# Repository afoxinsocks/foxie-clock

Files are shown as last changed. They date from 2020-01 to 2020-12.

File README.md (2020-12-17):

# Foxie Clock

## A Nixie-like, retro, RGB LED, Arduino-powered clock

Welcome to the Foxie Clock, a fully open-source RGB clock with nixie-like edge-lit acrylic digits. Or... an RGB pixel display clock, if you like!

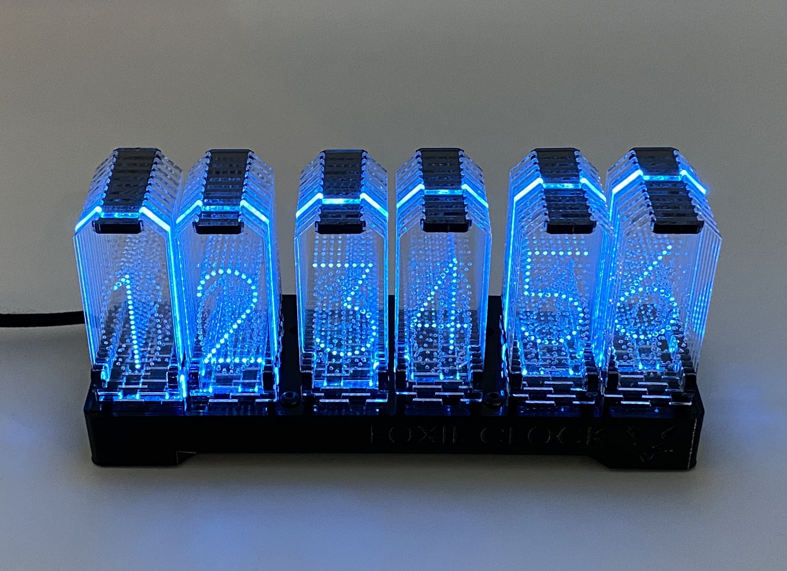
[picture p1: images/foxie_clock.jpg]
Foxie Clock Image

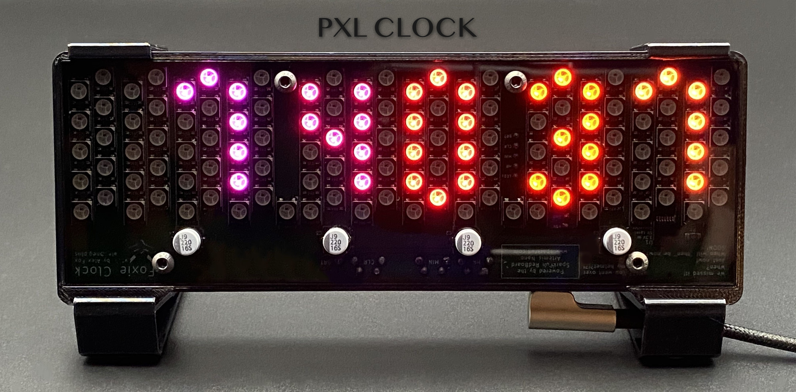
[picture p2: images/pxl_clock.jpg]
Foxie Clock Pixel Display


## Looks

With a look inspired by old nixie tubes and with capacitors protruding through the surface like vacuum tubes, the Foxie Clock is a fun, colorful way to display the time at your desk, office, or anywhere. Brightness, color, and time are all adjustable directly with 4 buttons on the back. [Using the clock is very easy](USAGE.md), with 4 buttons on the back providing various functionality for setting time, animation modes, colors, and brightness, 12/24h mode, PXL mode, and more.

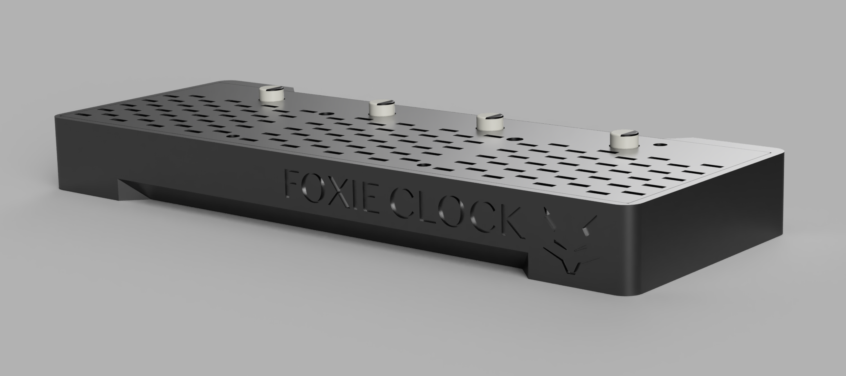
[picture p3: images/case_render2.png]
Foxie Clock Case Render Image2


# [Get your own](https://www.foxieproducts.com/)

Head [over to Foxie Products](https://www.foxieproducts.com/) to order your own Foxie Clock kit.

## 3D Print your own case or modify it yourself!

All .STL models and the full Fusion360 project and the .step files are also available for anyone wanting to make changes to the design more easily. Head over to [Thingiverse](https://www.thingiverse.com/thing:4114349) to download.

## Easy to assemble

The clock is [easy to assemble](ASSEMBLY.md) and looks beautiful when complete.

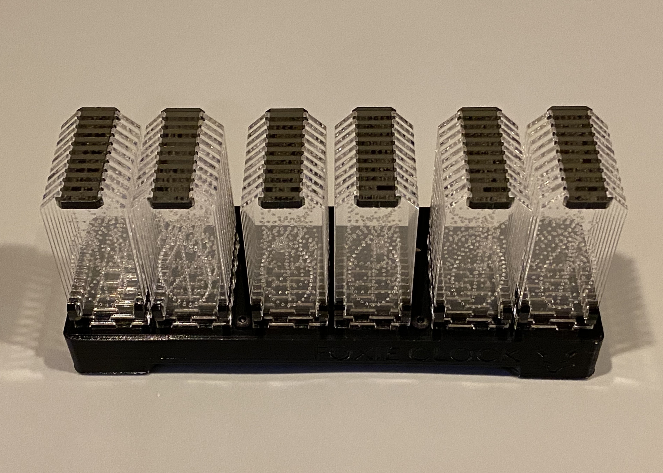
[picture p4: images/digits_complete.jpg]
Foxie Clock Case Assembled


The case is 3D printed and is included with the kit.

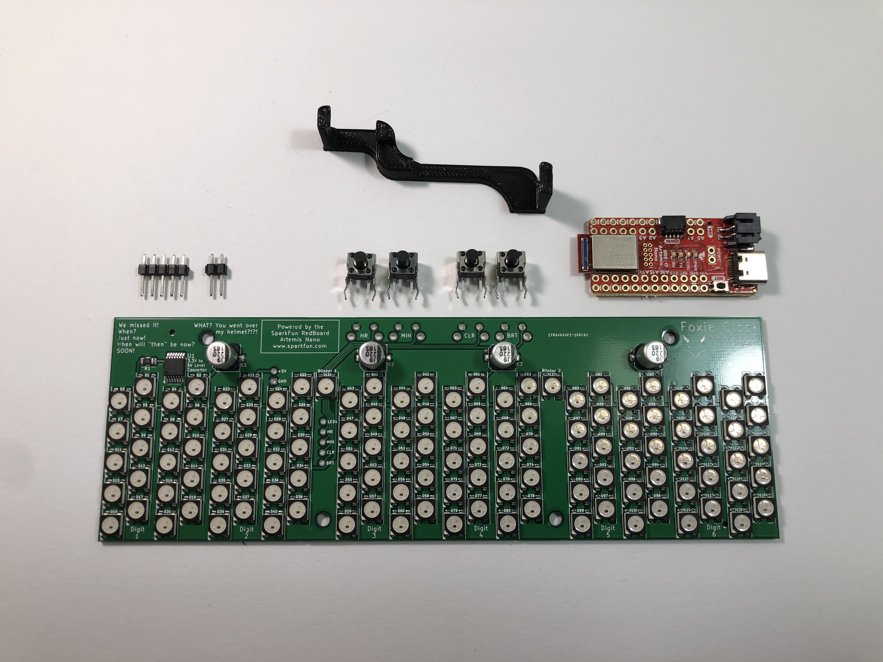
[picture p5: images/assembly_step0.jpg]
Foxie Clock Case Assembly


The circuit board can be ordered fully soldered, or if you like, you can solder the 4 buttons and RedBoard Nano yourself, using the plentiful pictures in the [electronics assembly guide](ELECTRONICS.md).

## Easy to hack

The Foxie Clock is powered by a SparkFun RedBoard Artemis Nano (https://www.sparkfun.com/products/15443), an extremely cool, fully Arduino-compatible board that supports Bluetooth LE 5.0 and much, much more. It is included in every Foxie Clock kit, along with everything you need (including USB-C cable) to get running.

## Fully Open Source

The Foxie Clock PCB and firmware were developed using Open Source software. The source code, laser cutting files, PCB design, and documentation for assembly are all freely available here.

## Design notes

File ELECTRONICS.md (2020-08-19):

# Electronics

Time to dust off your soldering skills, we've just got a few buttons to solder and finally need to attach the RedBoard Nano to the Foxie Clock PCB. 

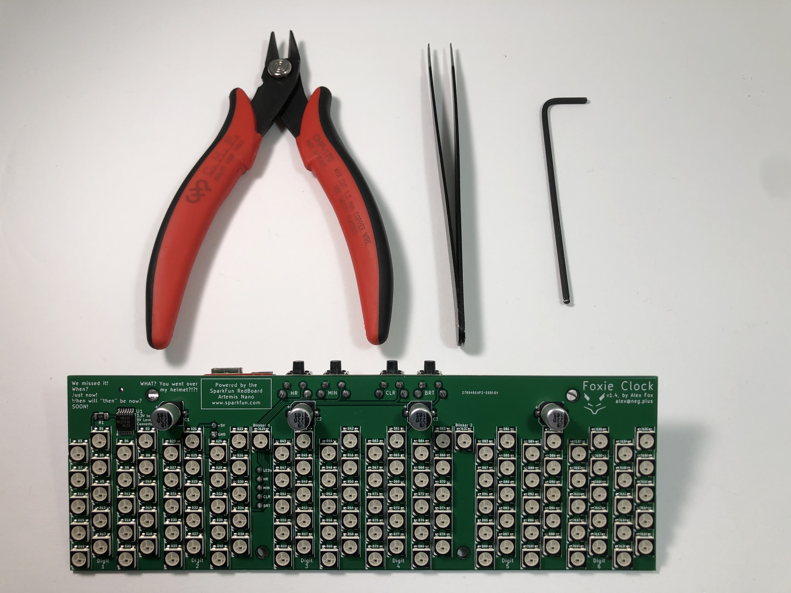
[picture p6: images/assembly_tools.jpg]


Included parts:
* One 2-pin header
* One 5-pin header
* 4 buttons
* One RedBoard Nano
* One "assembly helper"

**Note:** The clippers are necessary to trim the tops of the button pins, otherwise the lid will not sit correctly.

Parts

## Step 1

Insert the 4 buttons into the holes on the bottom of the PCB.

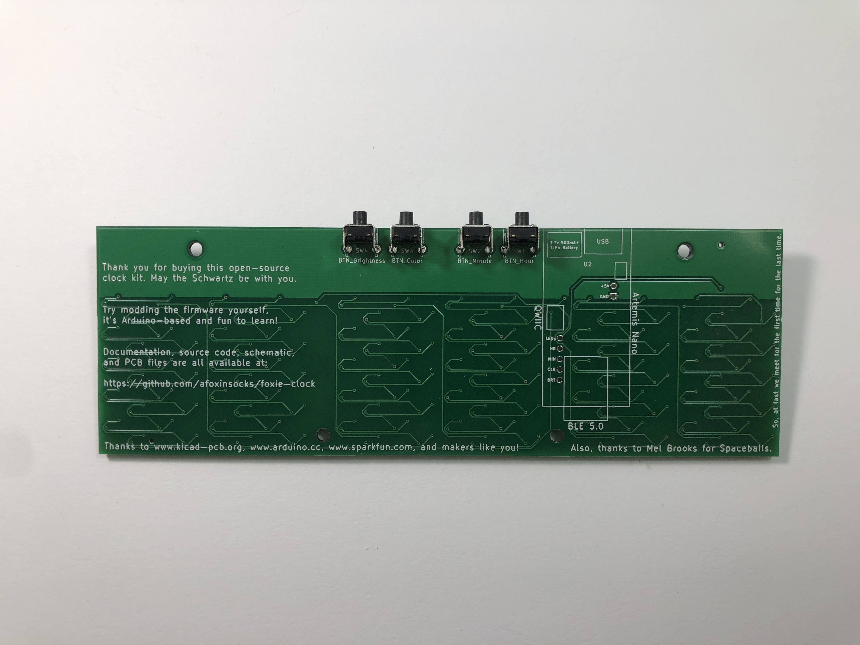
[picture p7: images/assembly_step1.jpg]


## Step 2

Ensure that the buttons are completely flat against the PCB.

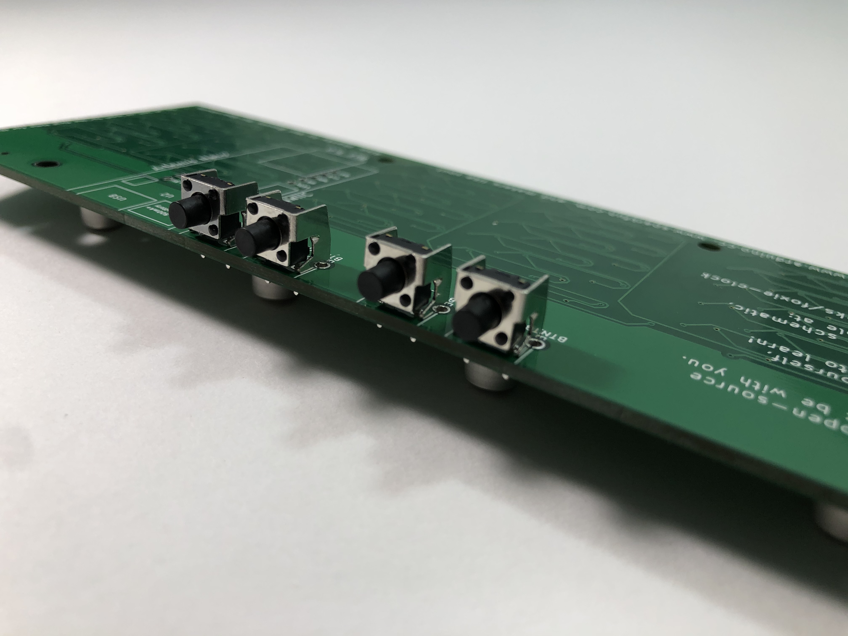
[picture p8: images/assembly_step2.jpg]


## Step 3

Turn the board over with the buttons in it. They are a snug fit and **should** stay in place.

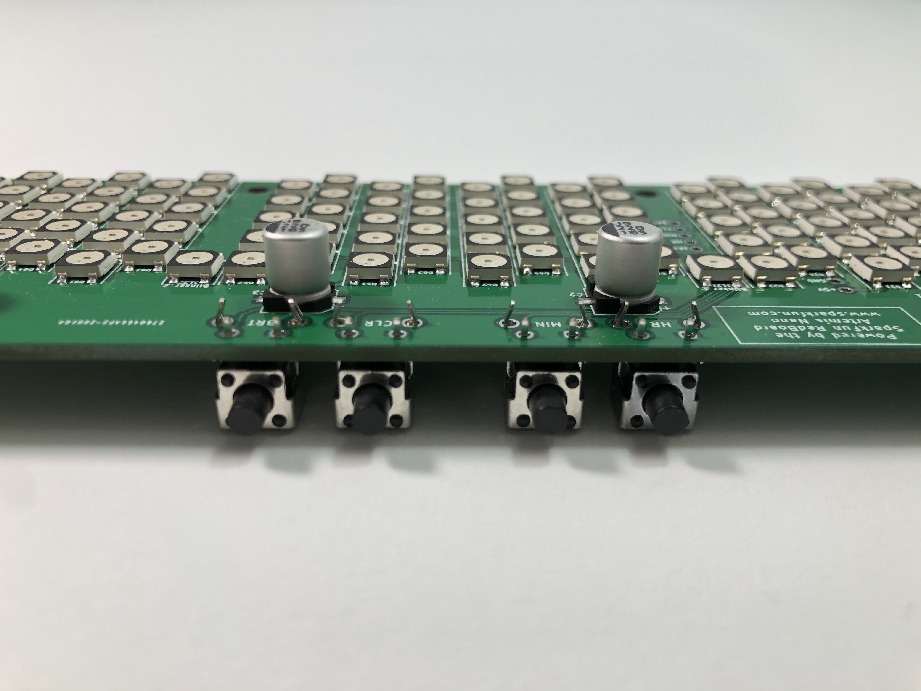
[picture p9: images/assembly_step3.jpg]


## Step 4

Begin by soldering one of the pins for each button. After doing so, double check that the buttons are still right against the PCB -- the tolerances on the back of the 3d printed case require these buttons to be exactly flush to the PCB. 

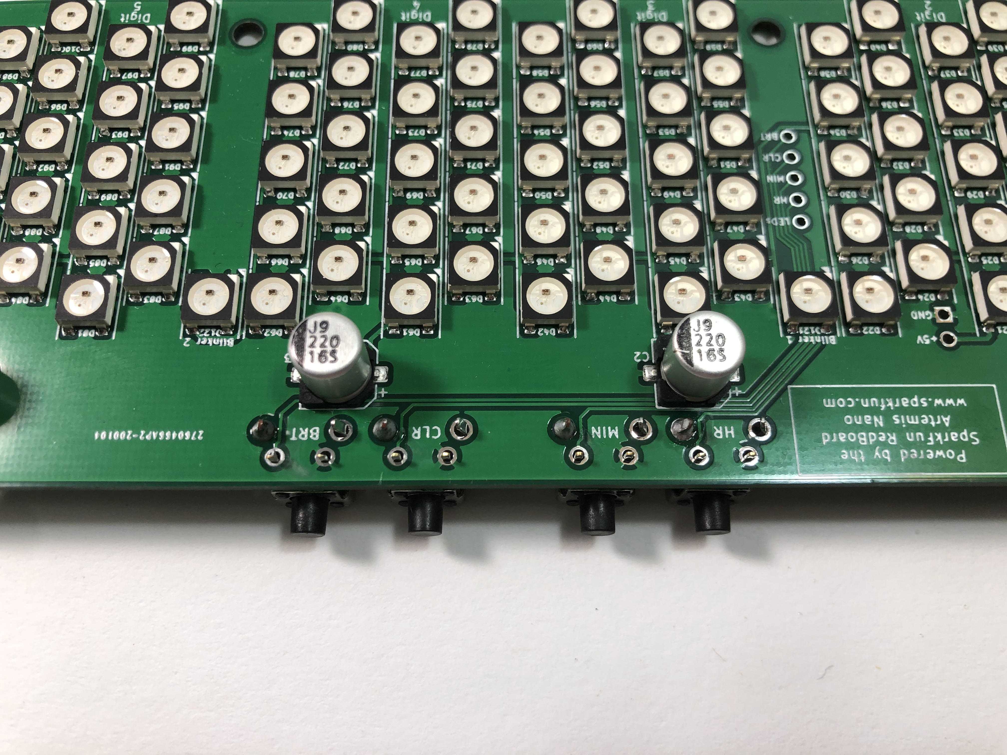
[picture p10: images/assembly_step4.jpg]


## Step 5

After verifying (and resoldering, if necessary) the single pin holding each of the buttons next to the PCB, go ahead and solder the other 3 pins for each button.

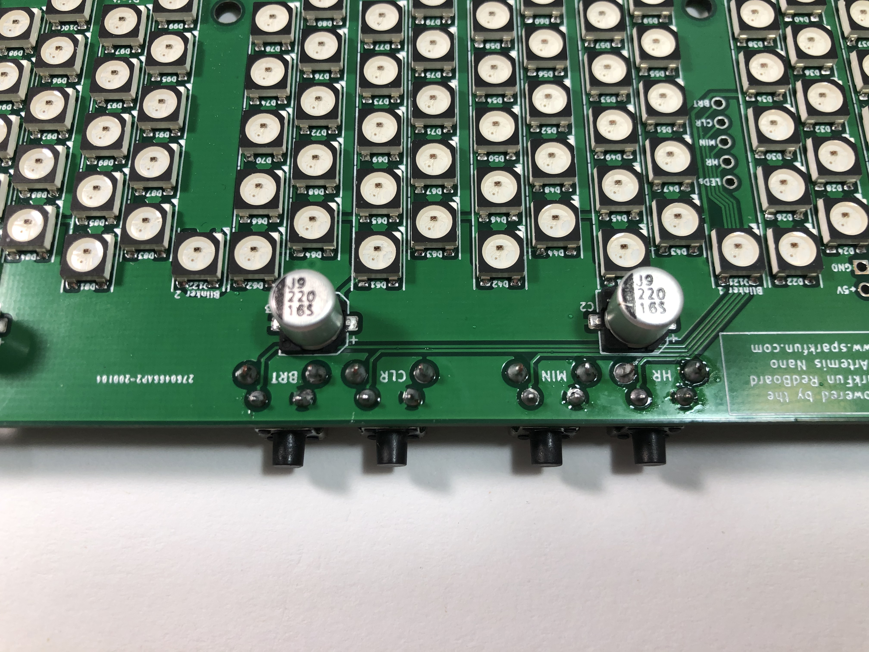
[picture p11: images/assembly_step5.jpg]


## Step 6

Prepare the RedBoard Nano by inserting the two headers into the *bottom* of the RedBoard (the side without the USB connector). The 2-pin header goes into the VIN and GND holes. The 5-pin header goes into the holes labled `6 A5 4 A3 A2`. **Do not solder yet!**

**NOTE**: Make sure the long pins of the jumpers are going through the RedBoard to the "top" side, otherwise you'll have to clip them off later when we trim the button pins.

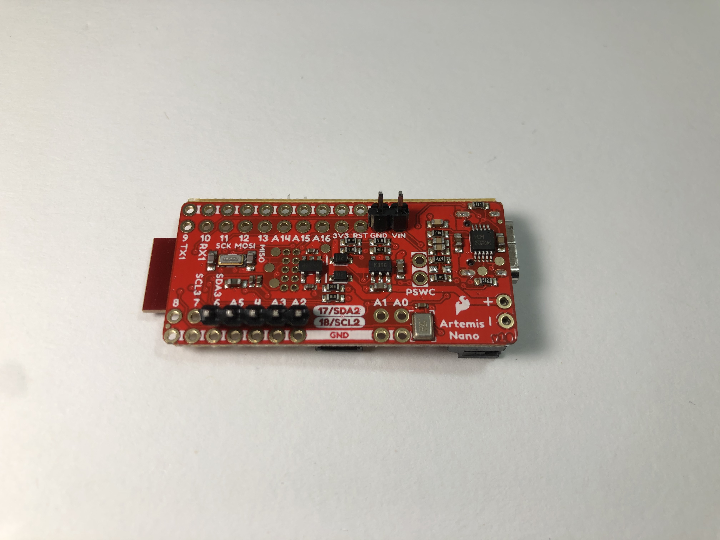
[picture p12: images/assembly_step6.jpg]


## Step 7

Holding the Foxie Clock PCB vertically, carefully insert the pins from the RedBoard into the Foxie Clock board, then set it down.

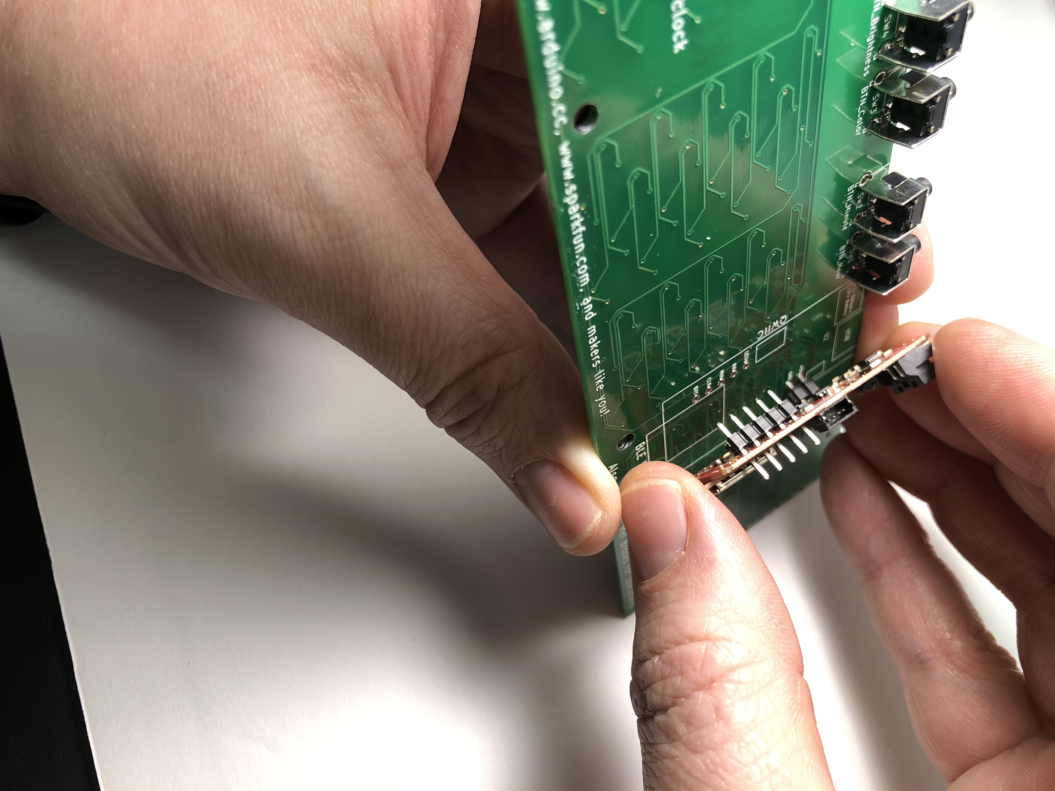
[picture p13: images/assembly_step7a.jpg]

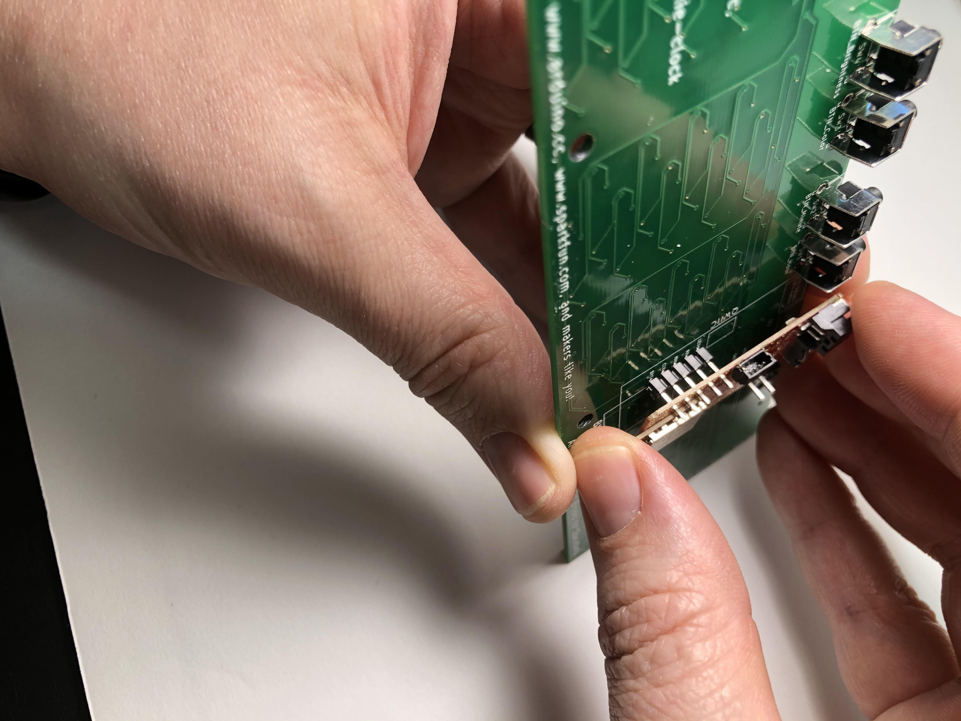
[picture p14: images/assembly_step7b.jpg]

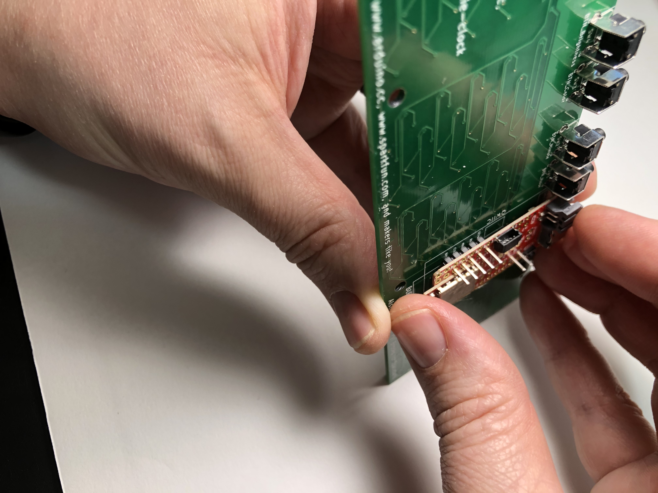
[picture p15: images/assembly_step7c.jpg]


## Step 8

Attach the Assembly helper to hold the RedBoard Nano to the PCB so that it is properly positioned. As with the buttons, it is important that the RedBoard be correctly positioned **before** soldering so that the USB port is in the correct place for
the USB port hole in the back of the case.

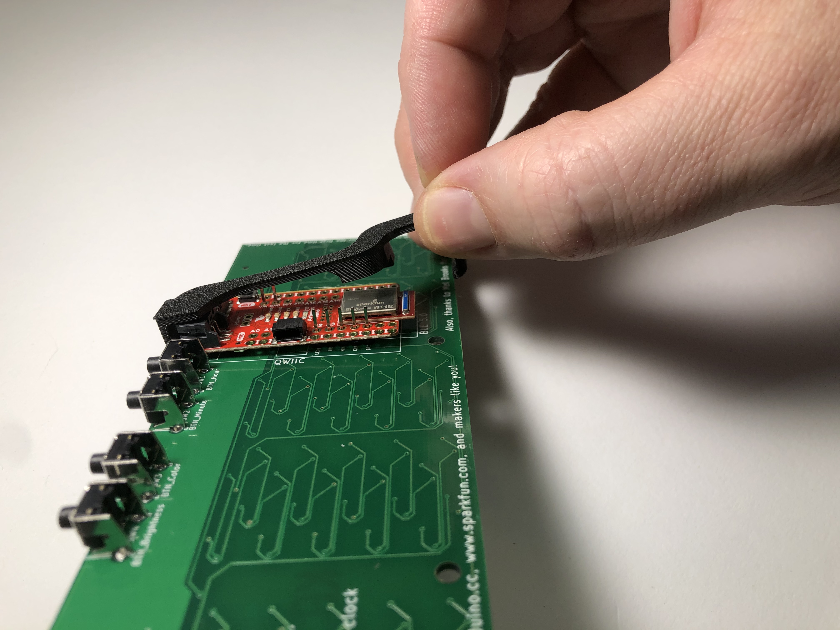
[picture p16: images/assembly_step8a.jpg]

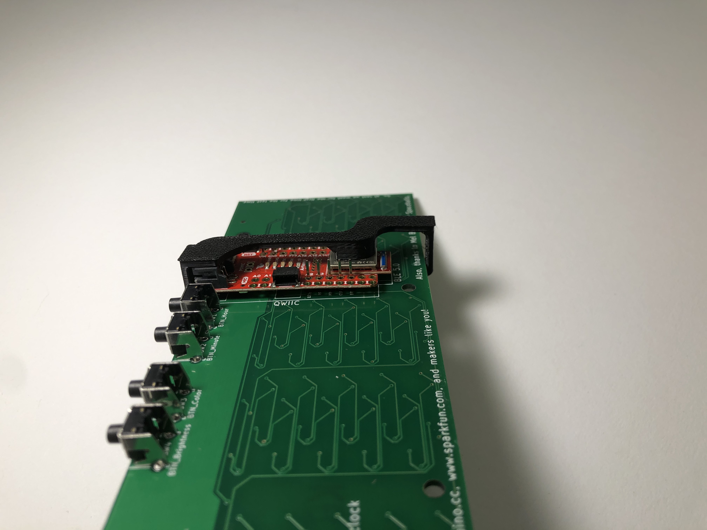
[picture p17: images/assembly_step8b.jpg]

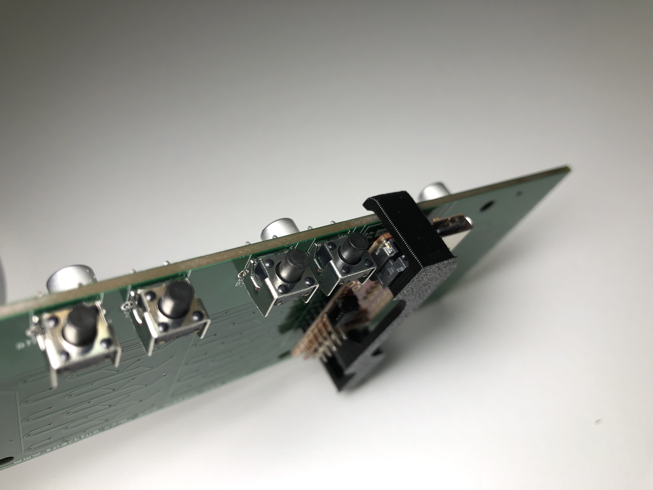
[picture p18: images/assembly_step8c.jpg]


## Step 9

Solder the 2-pin and 5-pin headers on the bottom of the RedBoard.

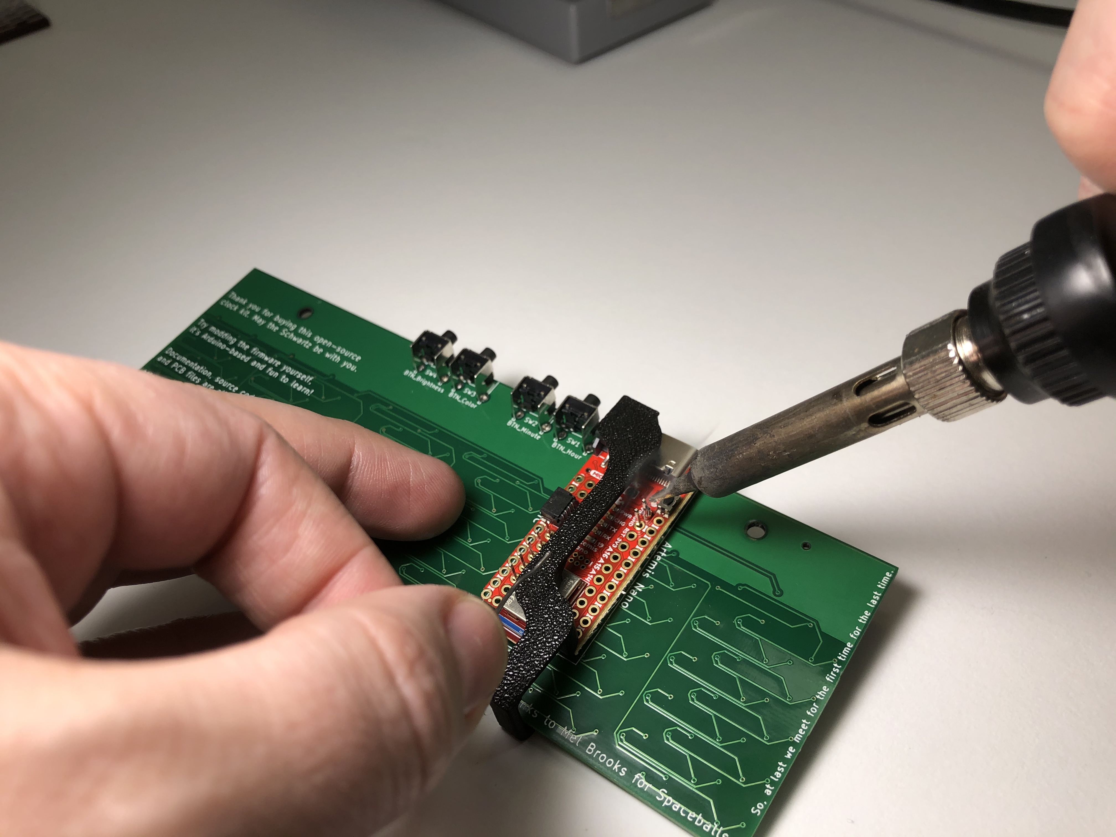
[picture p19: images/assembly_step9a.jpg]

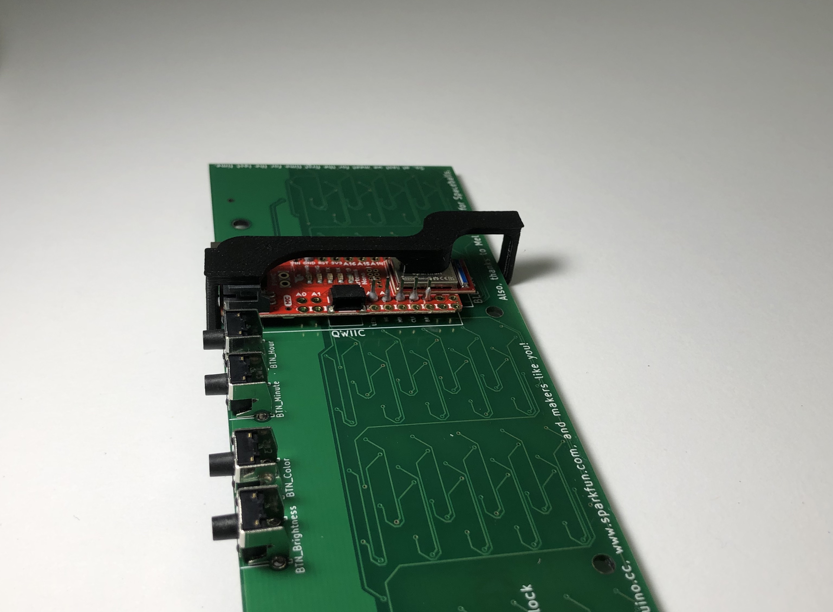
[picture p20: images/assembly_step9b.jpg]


## Step 10

Carefully turn the board over, keeping the assembly helper attached, and solder the 2-pin and 5-pin headers to the top of the PCB.

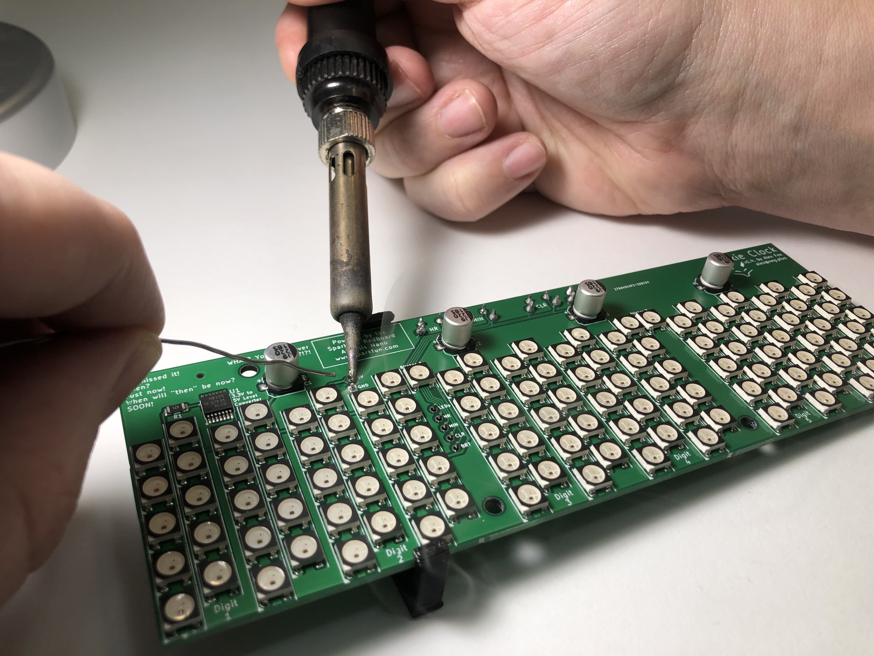
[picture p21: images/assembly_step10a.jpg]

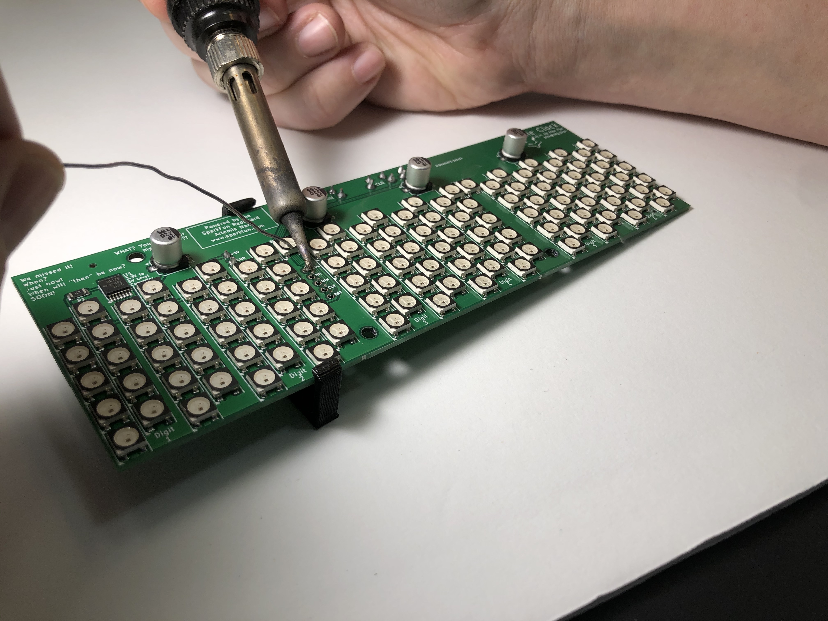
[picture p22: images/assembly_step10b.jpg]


## Step 11

Remove the assembly helper, and marvel at your perfectly placed RedBoard Nano on 7 little stilts.

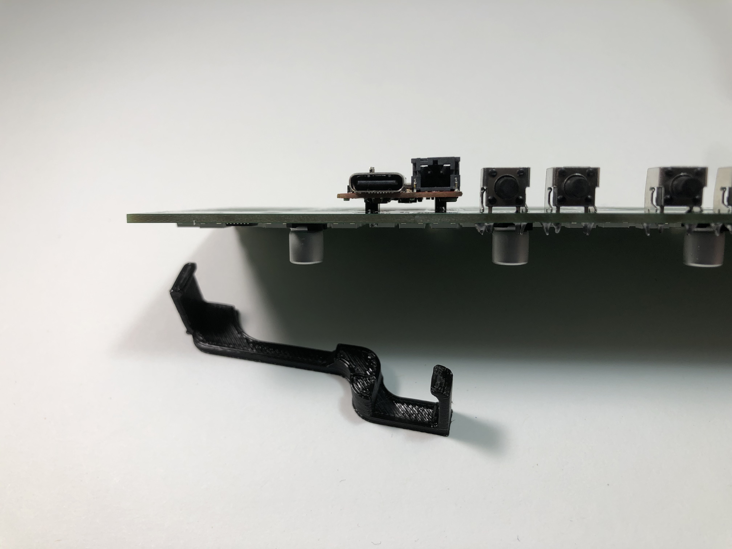
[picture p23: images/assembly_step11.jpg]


## Step 12

Trim the excess height of the button leads. 

**NOTE:** It is not important to get them flush. They just need to be trimmed to be about the same height as the LEDs, so that the lid sits correctly inside the case.

**NOTE:** It's a good idea to reflow the solder on these joints after being trimmed.

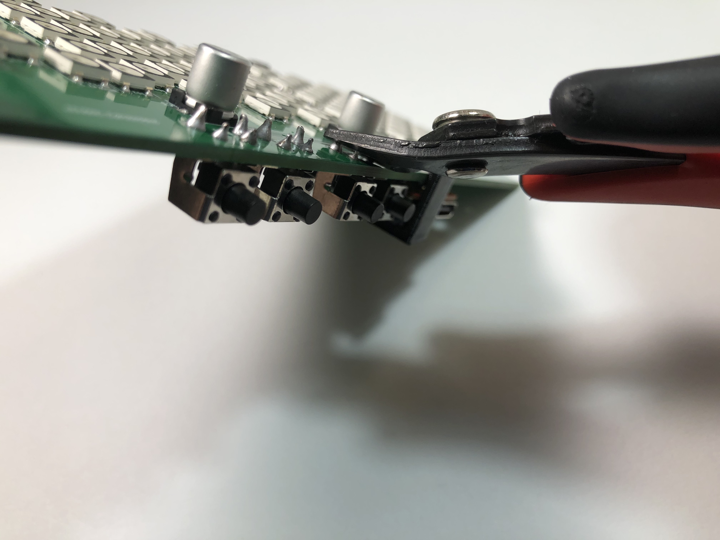
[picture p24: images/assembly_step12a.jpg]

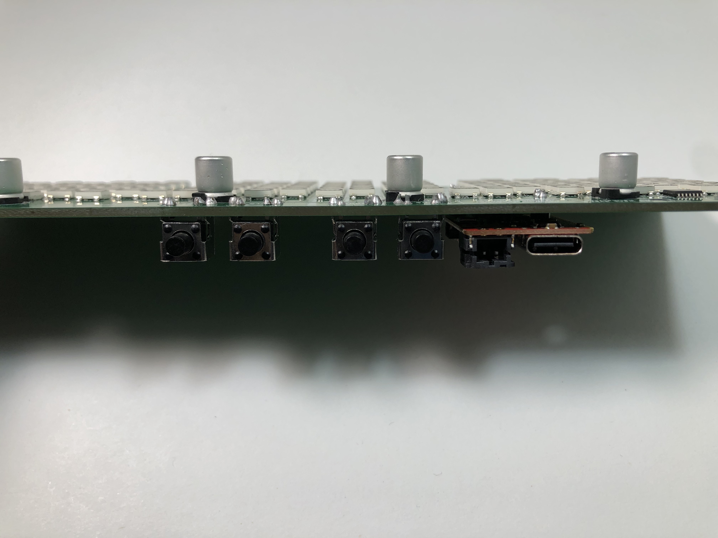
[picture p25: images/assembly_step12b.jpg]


## Step 13

Congratulations, the electronics are ready to go into the case!

Begin by placing the PCB in the rear top corners of the case.
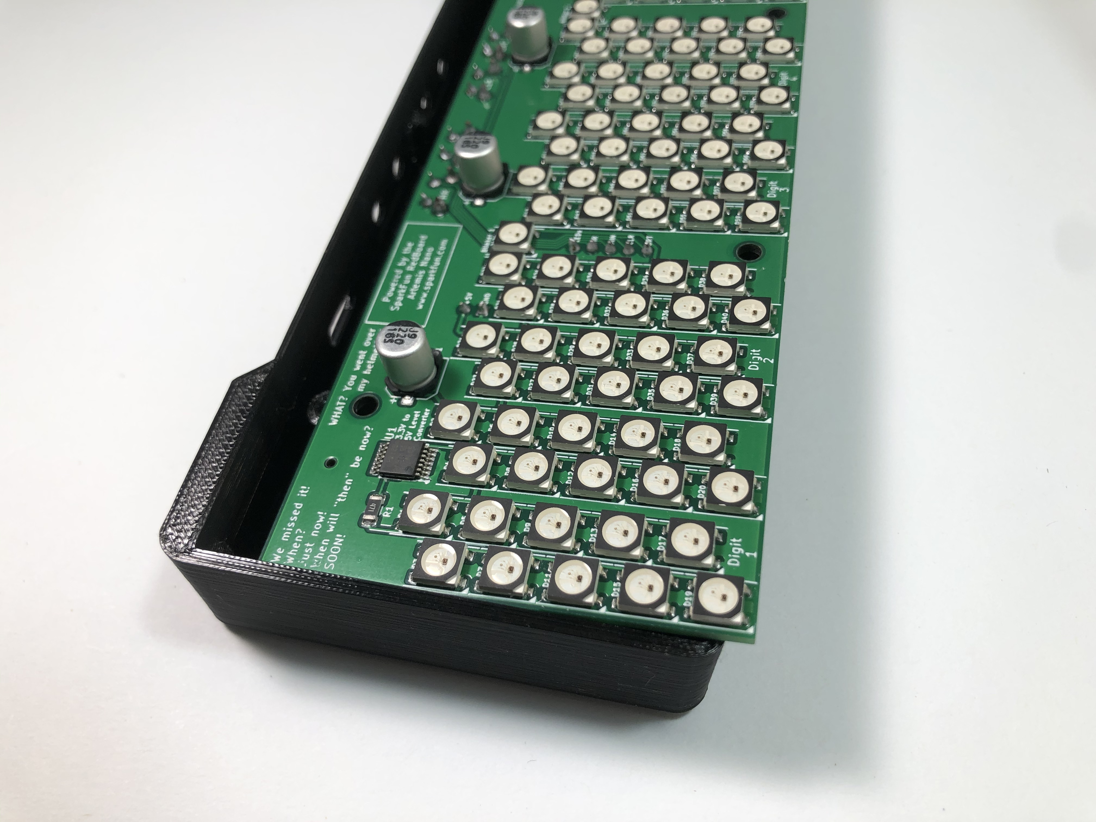
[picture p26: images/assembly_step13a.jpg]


Carefully push the buttons into the button holes.
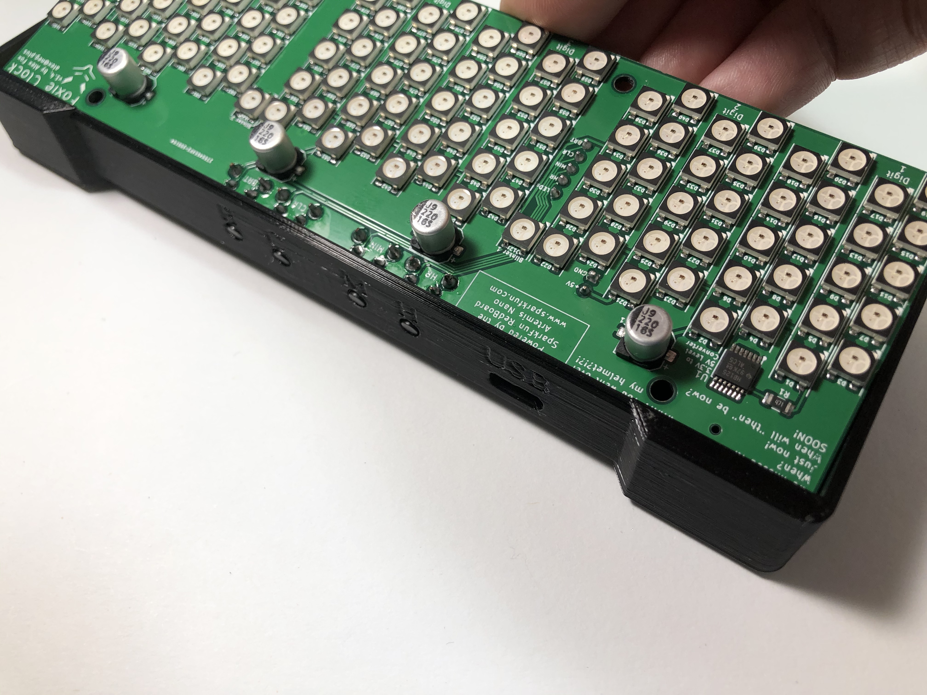
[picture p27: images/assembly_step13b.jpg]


The board should drop straight in at this point, if the buttons and Nano are close to being correctly placed.
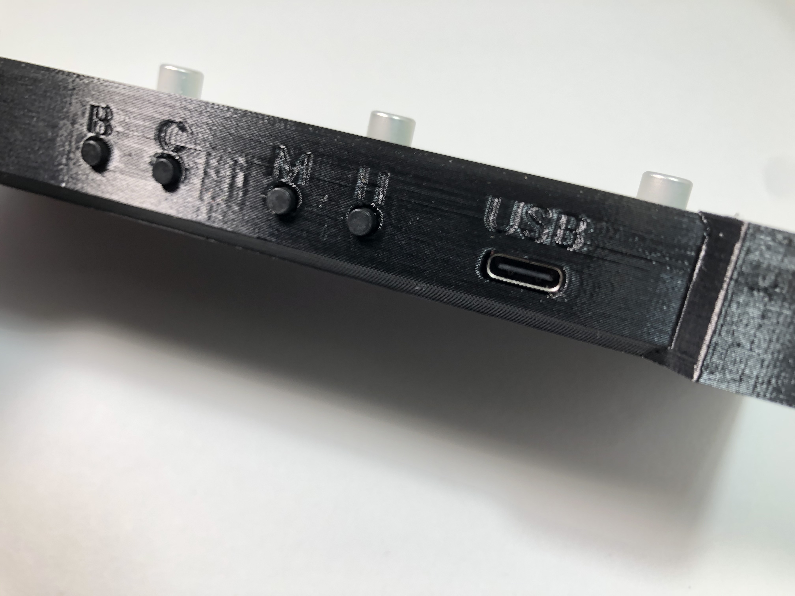
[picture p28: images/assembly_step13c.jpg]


Make sure that the board is completely flush with the inside back of the case.
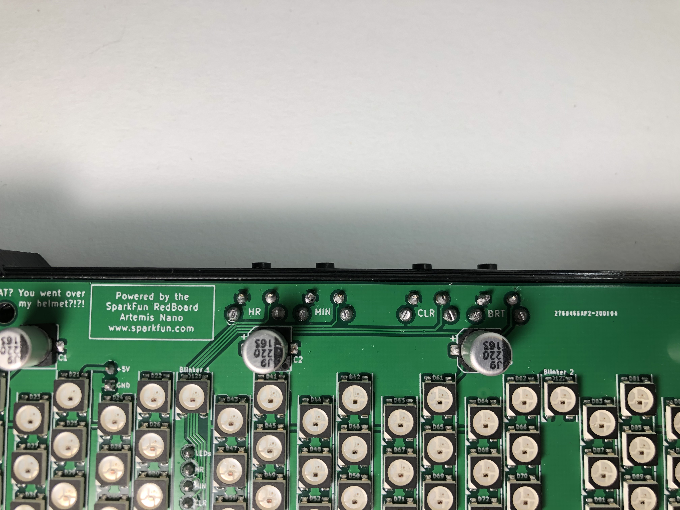
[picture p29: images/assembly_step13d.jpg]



You can now put the lid on top of the PCB and insert the 4 bolts, if desired. Make sure not to overtighten the bolts.

## Step 14

Firmware isn't yet programmed onto the RedBoard, [so let's take care of that now.](INSTALLING.md).

## Step 15
[Continue onto final assembly](ASSEMBLY.md)

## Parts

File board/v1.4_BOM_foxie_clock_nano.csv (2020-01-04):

Comment | Designator | Footprint | LCSC | LCSC
220uF | C1,C2,C3,C4 | Capacitor_SMD:CP_Elec_6.3x7.7 |  | C127327
WS2812B | D2,D1,D4,D3,D6,D5,D9,D10,D7,D8,D12,D11,D14,D13,D16,D15,D19,D20,D17,D18,D22,D21,D24,D23,D26,D25,D29,D30,D27,D28,D32,D31,D34,D33,D36,D35,D39,D40,D37,D38,D42,D41,D44,D43,D46,D45,D49,D50,D47,D48,D52,D51,D54,D53,D56,D55,D59,D60,D57,D58,D62,D61,D64,D63,D66,D65,D69,D70,D67,D68,D72,D71,D74,D73,D76,D75,D79,D80,D77,D78,D82,D81,D84,D83,D86,D85,D89,D90,D87,D88,D92,D91,D94,D93,D96,D95,D99,D100,D97,D98,D102,D101,D104,D103,D106,D105,D109,D110,D107,D108,D112,D111,D114,D113,D116,D115,D119,D120,D117,D118,D122,D121 | foxie_clock_nano:LED_WS2812B_PLCC4_5.0x5.0mm_P3.2mm |  | C114586
470 | R1 | Resistor_SMD:R_1206_3216Metric |  | C25383
BTN_Hour | SW1 | Button_Switch_THT:SW_Tactile_SPST_Angled_PTS645Vx58-2LFS
BTN_Minute | SW2 | Button_Switch_THT:SW_Tactile_SPST_Angled_PTS645Vx58-2LFS
BTN_Color | SW3 | Button_Switch_THT:SW_Tactile_SPST_Angled_PTS645Vx58-2LFS
BTN_Brightness | SW4 | Button_Switch_THT:SW_Tactile_SPST_Angled_PTS645Vx58-2LFS
SN74AHCT125N | U1 | Package_SO:TSSOP-14_4.4x5mm_P0.65mm |  | C36365
Artemis-Nano | U2 | foxie_clock_nano:Artemis-Nano

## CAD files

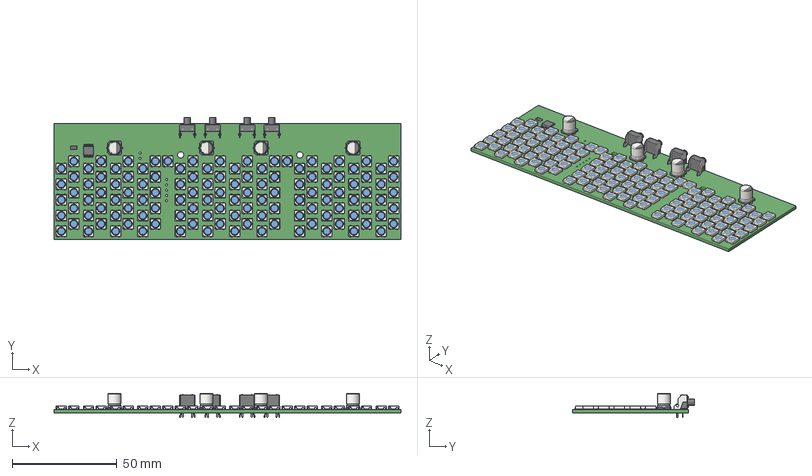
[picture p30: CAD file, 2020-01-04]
board/foxie_clock_nano_v1.step
166.0 x 58.5 x 11.7 mm

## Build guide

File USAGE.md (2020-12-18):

# How to use the clock

## Setting the time:
1. Hold H/Hour button down for 1+ seconds to enter Set Time mode (The H button is the closest to the USB port)
2. Digit colors will change and the seconds will stop counting
3. Use H and M buttons to set the correct Hours and Minutes -- Holding M will advance minutes quickly. Note that H does not have the same fast functionality.
4. Hold H button down again for 1+ seconds to return to normal mode - the seconds will resume counting and the clock color will change back to the previous setting.

## Changing the brightness
Press the `B` button to set the brightness. There are 8 levels, and the current brightness is remembered when powering off the clock.

## Changing the color
The `C` button is typically used for changing the color of the digits, but its use depends on the animation mode the clock is currently using.

### Animation modes:
Animation modes can be changed by pressing the `M` button while not in `Set Time` mode. The current animation mode number will be displayed after each button press.

* ANIM_NONE (0): No animation, and pressing the C button will manually change the colors for all digits at once. The current color setting is saved when changed.
* ANIM_ZIPPY(1): An animation that causes movement through all the numbers every time a number changes.
* ANIM_GLOW (2): Similar to ANIM_NONE, except the digits briefly dim and glow every couple seconds. C button changes colors for all digits at once
* ANIM_CYCLE_COLORS (3): The colors will cycle across the digits as each second changes and the C button will not do much other than briefly flash a color.
* ANIM_CYCLE_FLOW_LEFT (4): The color of the furthest right digit will cycle each second and as each digit rolls from 9 back to 0, that digit's color will be copied to the left.
* ANIM_RAINBOW (5): All digits will continuously gently cycle colors while the clock is running.
* ... more modes are coming!

Changing the animation mode will be possible via the mobile app within the coming months, and can also be manually set via the  `setup()` function in `firmware.ino` and then [re-upload the firmware](INSTALLING.md).

## Toggling between edge-lit and PXL mode
Hold M+C for 1 second to toggle. This is useful when you switch between the acrylic digit base and the PXL cover.

## Toggling 12/24H mode
Hold H+M for 1 second.

## Flipping the display
Hold C+B for 1 second to toggle. This is useful if you want to put your digits in the reverse order, to keep the buttons at the front. Also, useful for PXL mode.

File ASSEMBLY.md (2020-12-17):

# Electronics

If your kit requires soldering the buttons and RedBoard Nano to the Foxie Clock PCB, head to 
[the electronics assembly instructions](ELECTRONICS.md) and complete that step first.

# Digits

For digit assembly, the **most important** thing to remember is to keep the digits clean. If the digits get
fingerprints on them, it becomes difficult to see the numbers through several layers. They can be carefully
cleaned with lens wipes. All kits include 2 nitrile gloves (non-powder, non-latex) to assist with assembly.

You'll need the fully assembled Foxie Clock board, a 2mm hex wrench, a utility knife or Xacto knife, and finally, sharp tweezers are extremely helpful. 

## Step 1

Set out the 6 sets of digits and put on the nitrile gloves gloves. This part is a little tedious but if you are careful, you can peel the film off each side as one piece, in less than a minute. Ideally, *do not* break the digits apart before this step.

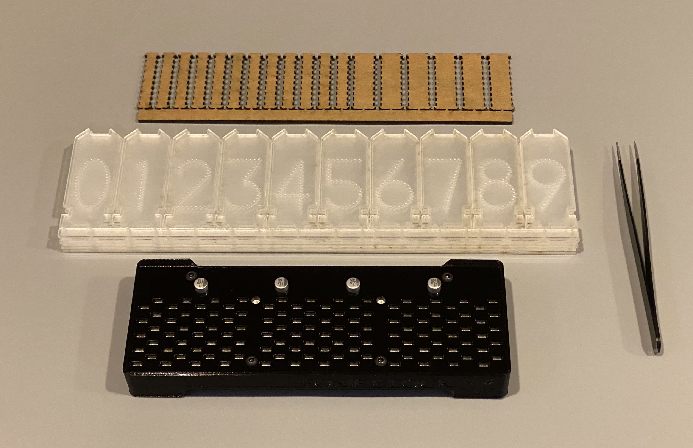
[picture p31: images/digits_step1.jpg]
Lay out stacks of digits


## Step 2

Carefully peel back the film on the "rail" and then peel carefully along the rail to the other side. After that, peel toward the top of the digits.

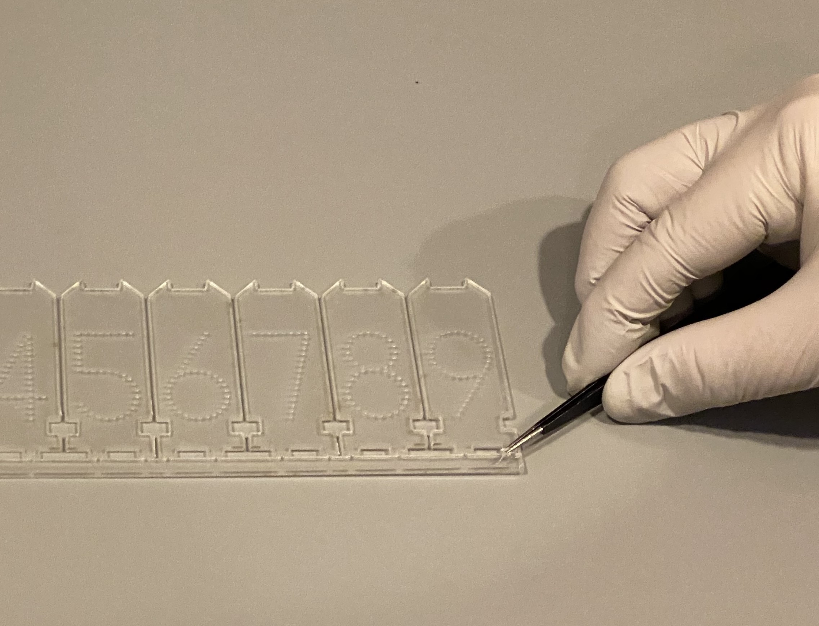
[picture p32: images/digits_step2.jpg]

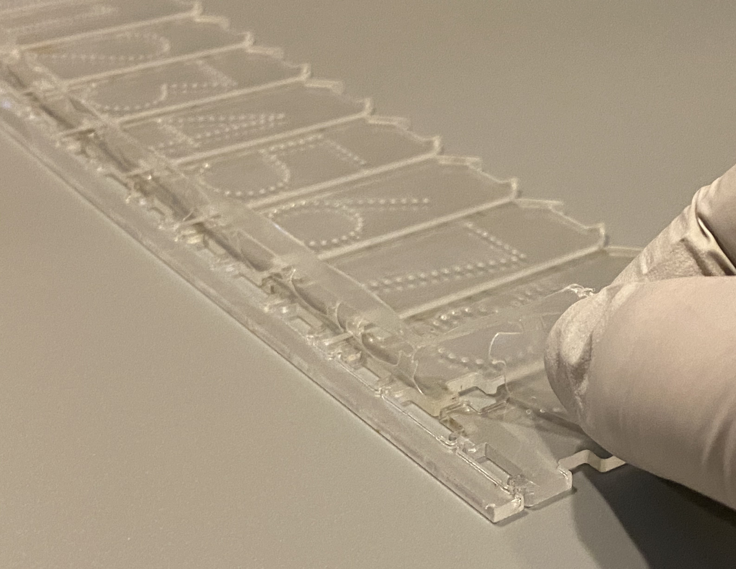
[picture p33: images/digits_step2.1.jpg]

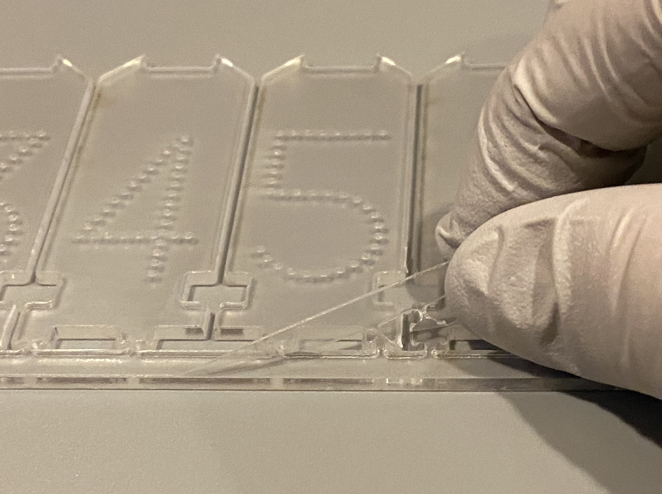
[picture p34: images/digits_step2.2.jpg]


## Step 3

Peel the protective paper off the digit block supports, using the same method as with the digits -- start with the rail. 

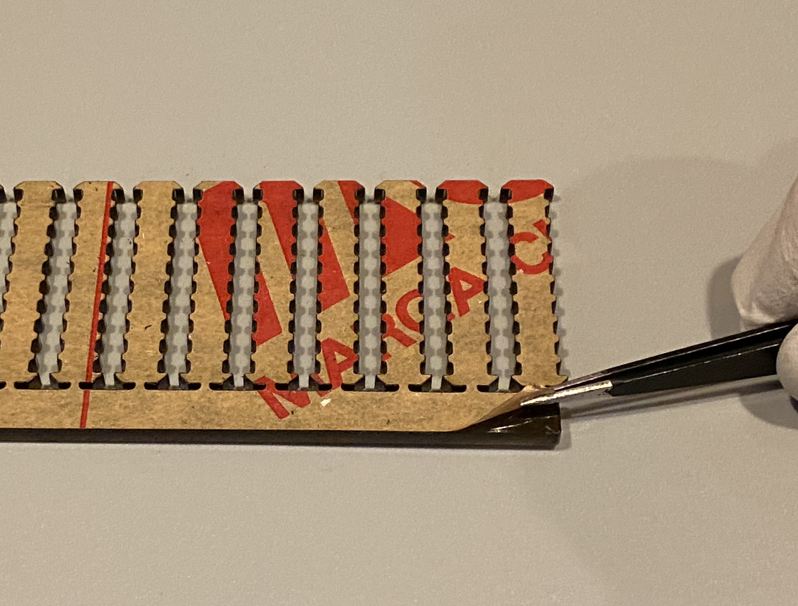
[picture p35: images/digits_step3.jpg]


## Step 4

The notches and notch supports are a tight fit. Make sure to insert the notch supports as flat as possible, so that you do not *crack* the digits.

It's easiest to carefully go along a set of digits, breaking them off the rail one by one to insert into the TOP (wide) notch support. After you have all 10 digits off the rail, then place one of the side supports in, then the other one. It will require some pressure to get the side (narrow) notch supports in all the way -- put the digits down on a table with the side notch support fitted partially (make sure it is not twisted!) into the notch, then press from the other side of the digits directly down toward the table.

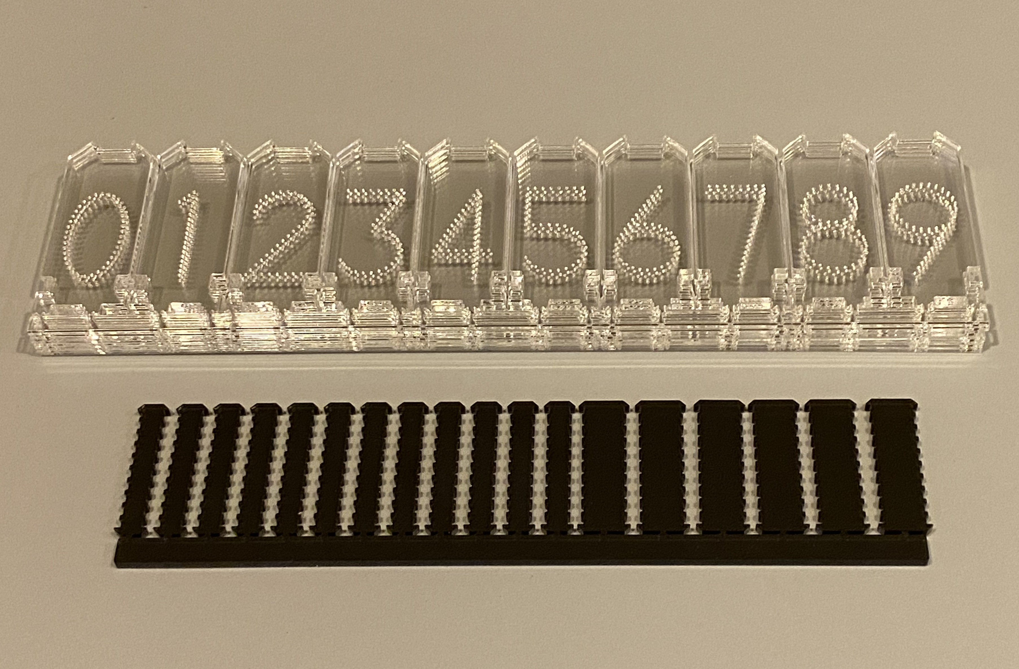
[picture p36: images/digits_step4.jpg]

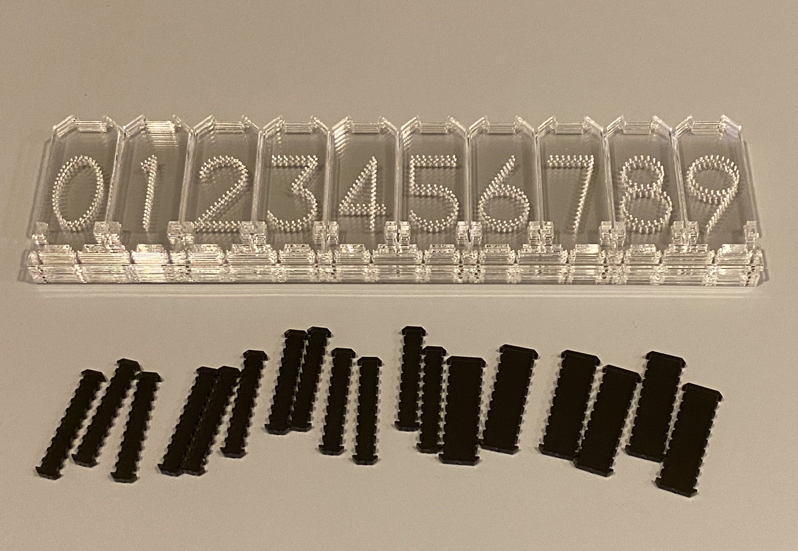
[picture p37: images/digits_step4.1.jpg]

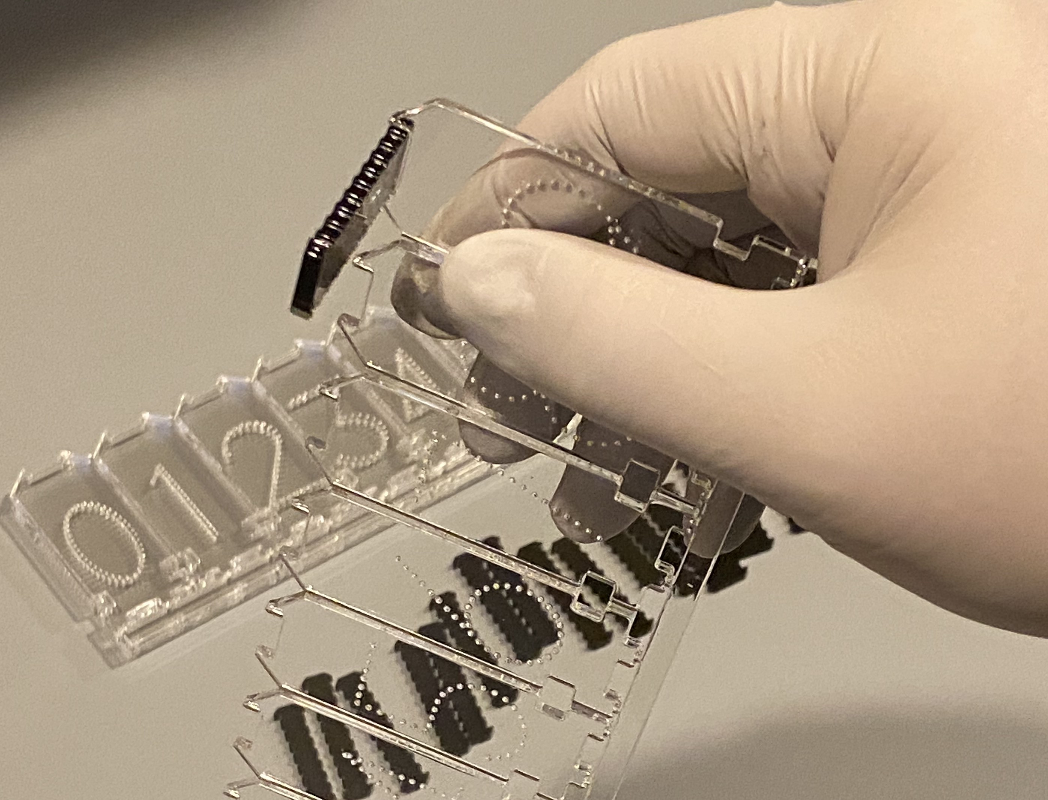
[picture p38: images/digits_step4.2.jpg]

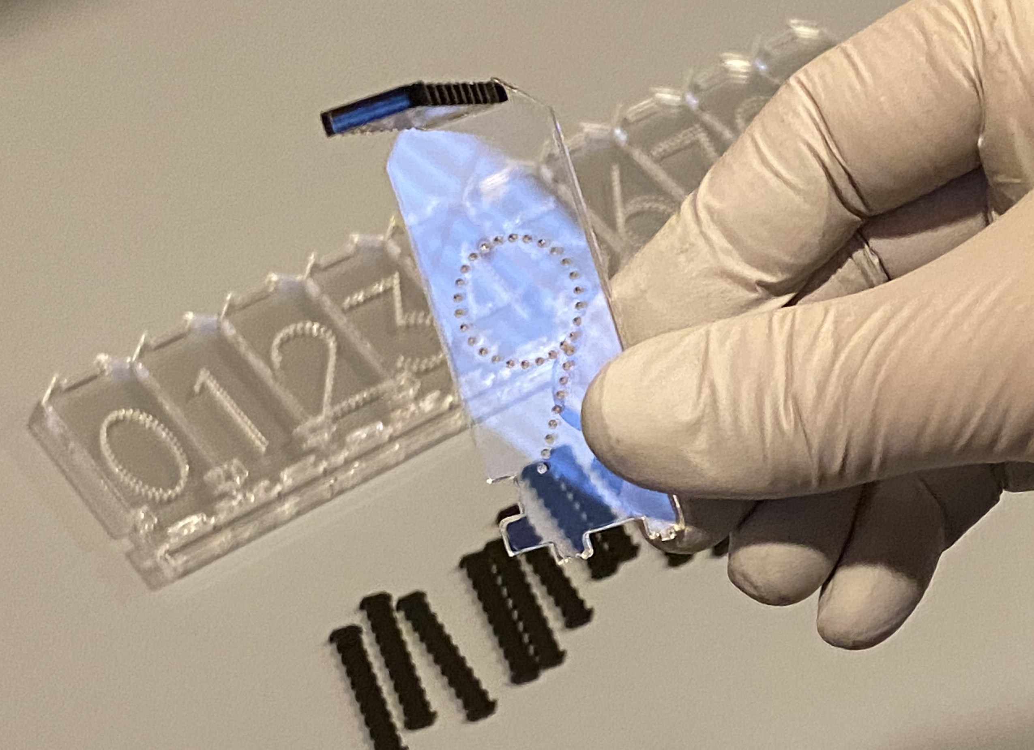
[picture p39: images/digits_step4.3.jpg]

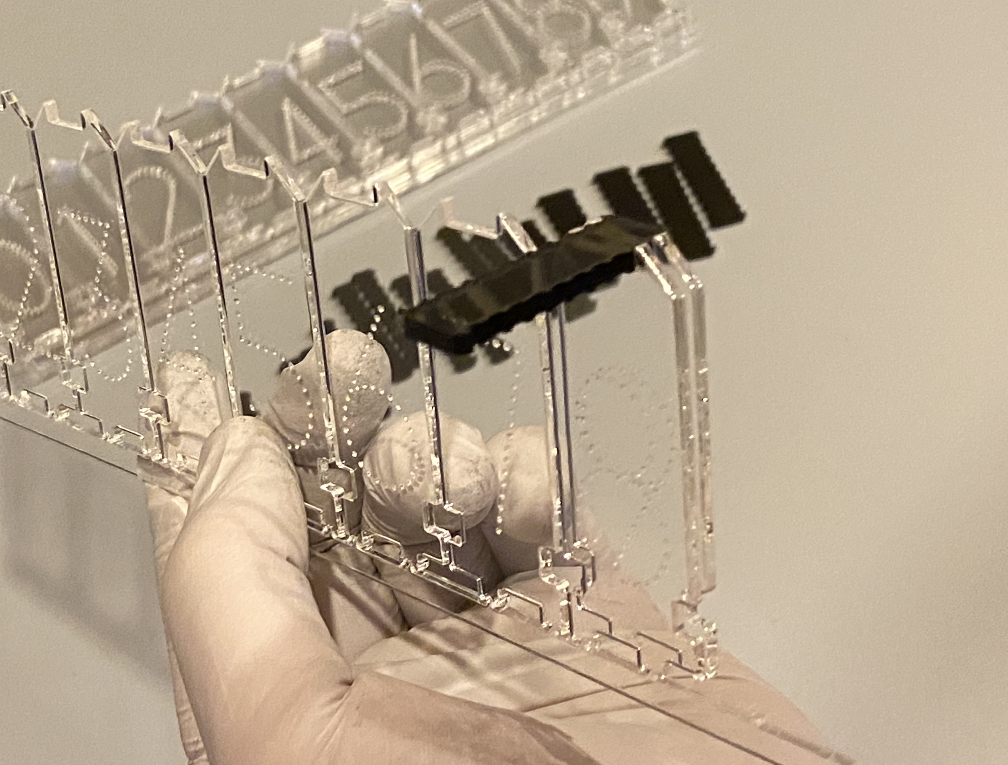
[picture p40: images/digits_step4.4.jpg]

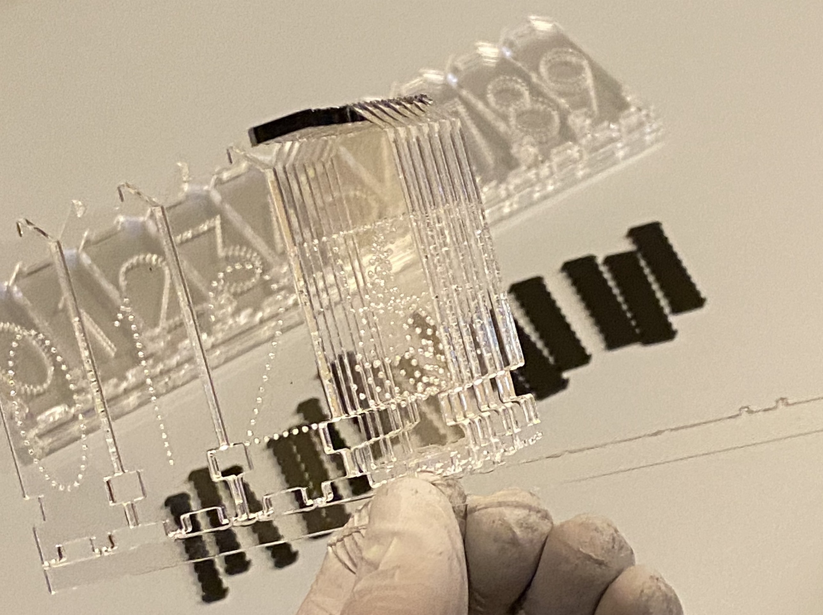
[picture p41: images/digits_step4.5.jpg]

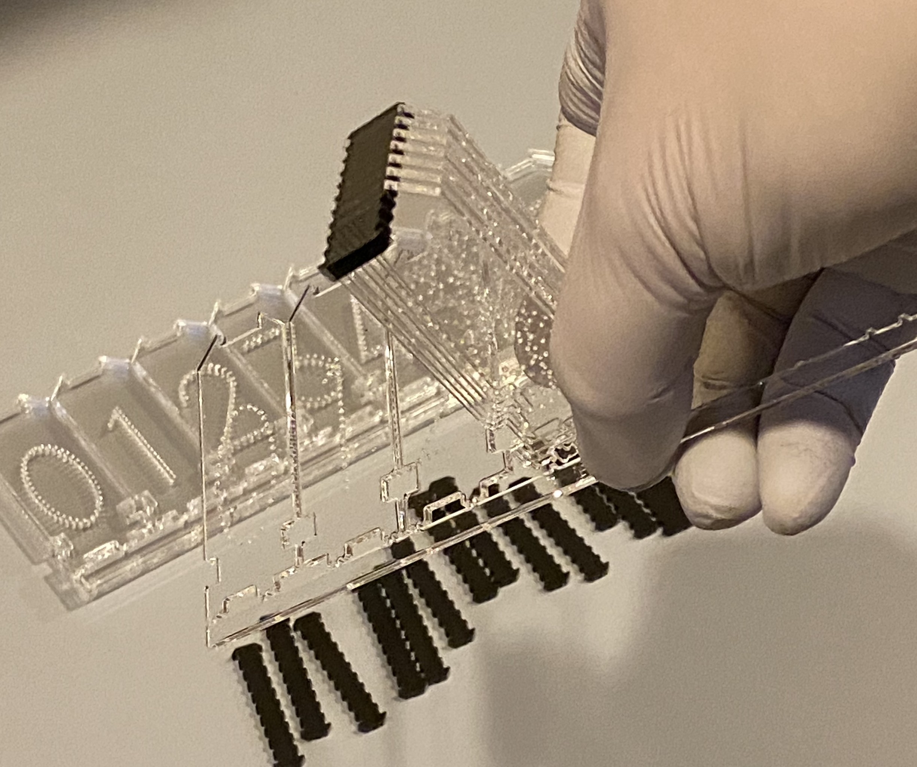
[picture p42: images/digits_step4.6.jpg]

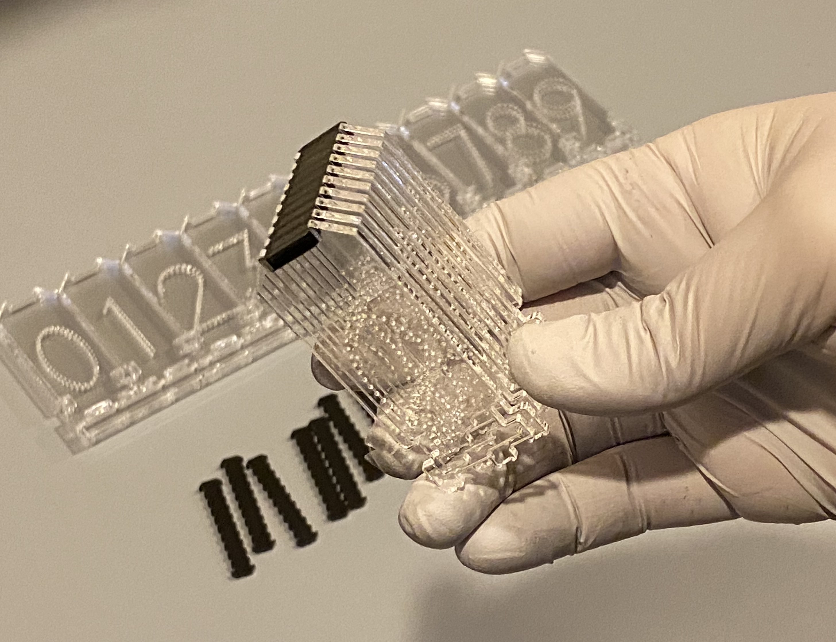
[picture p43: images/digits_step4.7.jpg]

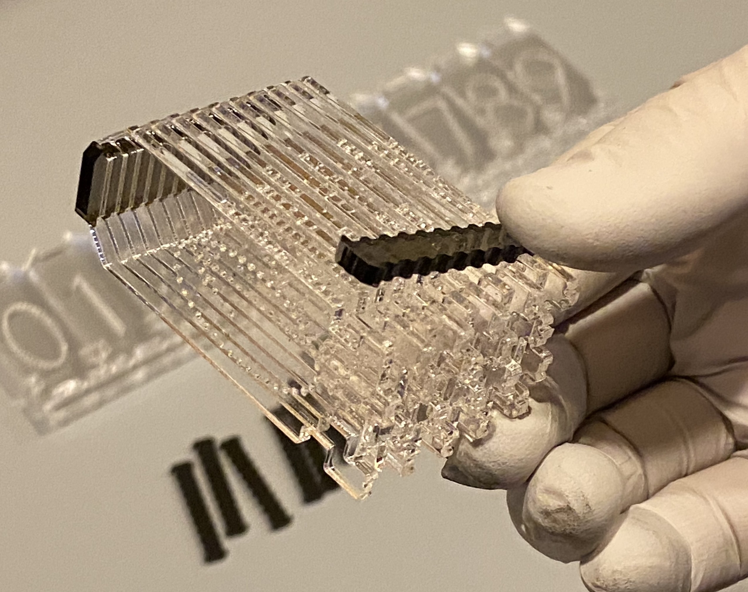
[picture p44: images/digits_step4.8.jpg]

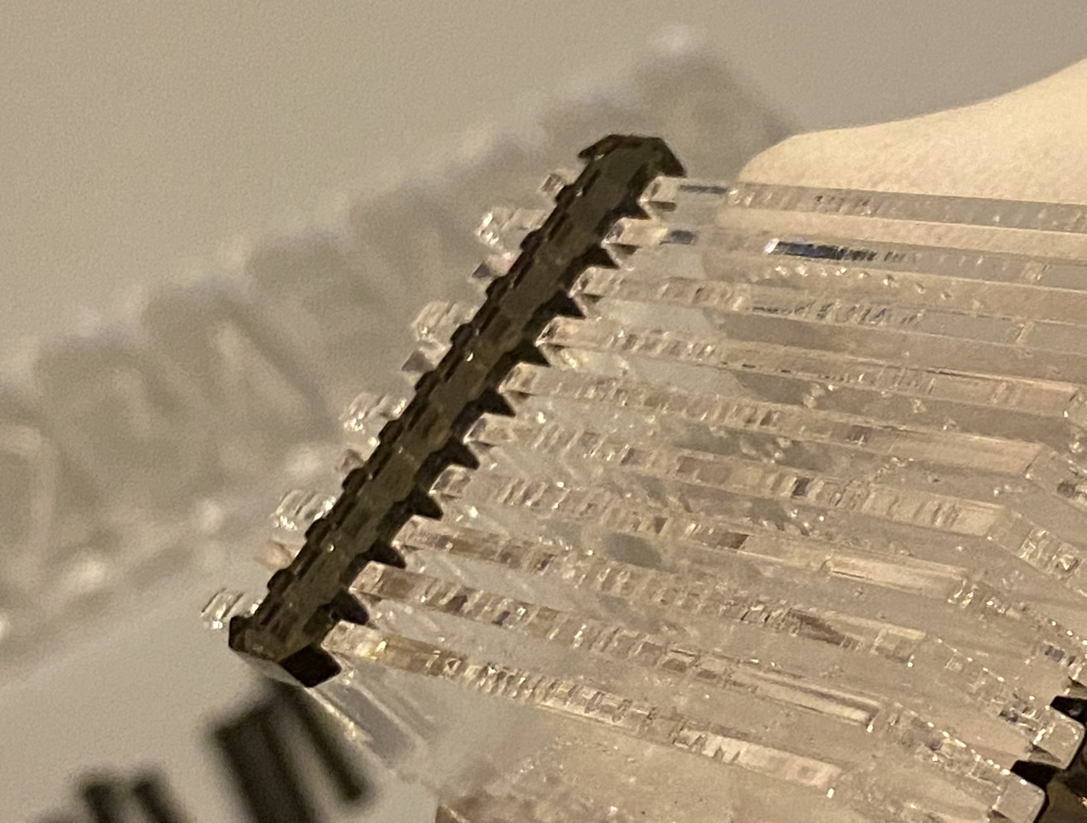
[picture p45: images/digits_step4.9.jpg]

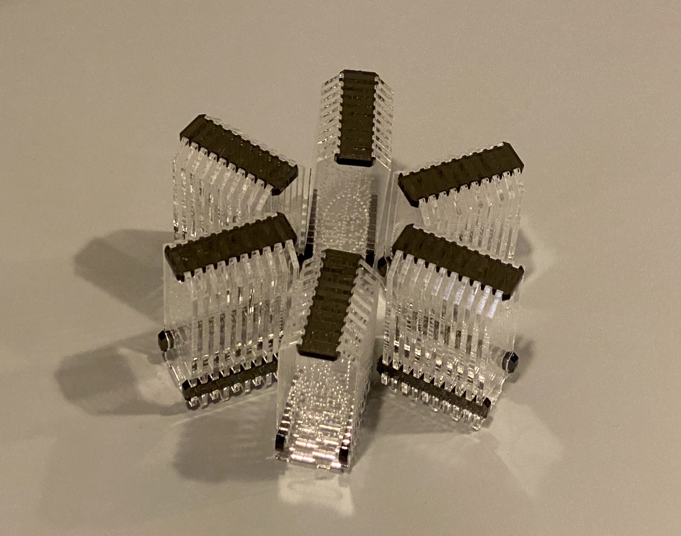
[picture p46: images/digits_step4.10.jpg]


# Congratulations!

If you haven't already powered up the clock, find a USB-C cable and try it now. [Installing the latest firmware is straight-forward](INSTALLING.md). 

Finally, [set the time, colors, and brightness](USAGE.md).



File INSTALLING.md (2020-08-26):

# How to install/update the firmware

So it's time to update the firmware, for the first time, for the last time. Hopefully not the last time!

## Prepare your computer to talk to the RedBoard Nano
1. Install the Arduino IDE on your computer from https://www.arduino.cc/en/Main/Software. 
   At this moment, 1.8.13 is the latest version.
2. Open the Arduino Preferences menu (File->Preferences or Arduino-Preferences on macOS)
3. Enter `https://raw.githubusercontent.com/sparkfun/Arduino_Boards/master/IDE_Board_Manager/package_sparkfun_index.json` 
   into the Additional Boards Manager URLs -- this is to allow Arduino to download the RedBoard support in the following steps.
4. Click OK to close the Preferences window
5. Open `Tools->Board` and select `Boards Manager`
6. Search for `RedBoard Nano` to install the `SparkFun Apollo3 Boards` and select `Install`. 
   At this moment, 1.1.2 is the latest version of the Apollo3 Board support from SparkFun and is confirmed to work with the latest Foxie Clock firmware.
7. Select `Tools->Board->SparkFun RedBoard Artemis Nano`
8. Select `Tools->Programmer->Ambiq Secure Bootloader`
9. Make sure your Foxie Clock is plugged into your computer with a USB-C cable.
10. Select `Tools->Port` in Arduino and choose the correct port for your Foxie Clock. 
   On **most** platforms, this will have "wch" at the beginning of the serial port name.
   If there is more than one available port, you can unplug the clock, open `Tools->Port` to see what is there,
   then plug in the clock again and select the newly available port. 
   
   Note: On some operating systems (such as macOS), you may need to install WCH's CH340 drivers and **reboot** for the board support
   to detect the correct serial port. 
   See [SparkFun's How to Install CH340 Drivers](https://learn.sparkfun.com/tutorials/how-to-install-ch340-drivers)
   for more information.
   
11. **OPTIONAL, but highly recommended:** Select `Tools->Burn Bootloader` to write the latest version of SparkFun's bootloader 
   to the Nano -- this is still important for the Artemis boards for Arduino to be able to write the firmware reliably.

### For more help with the RedBoard Nano:
[SparkFun's Hookup Guide for the SparkFun RedBoard Artemis Nano](https://learn.sparkfun.com/tutorials/hookup-guide-for-the-sparkfun-redboard-artemis-nano)

[SparkFun's Artemis Development with Arduino](https://learn.sparkfun.com/tutorials/artemis-development-with-arduino)

## Installing/updating the latest firmware
The best thing is to `git clone https://github.com/afoxinsocks/foxie-clock` to your local computer, then you can simply `git pull` to get the latest changes at any time.
1. In Arduino IDE, open `foxie-clock/firmware/firmware.ino`
2. Make some changes, if you want!
3. Select `Sketch->Upload` 
4. Remember, you can always undo any local changes easily with git in case you really mess it up. Don't be afraid to try new things!

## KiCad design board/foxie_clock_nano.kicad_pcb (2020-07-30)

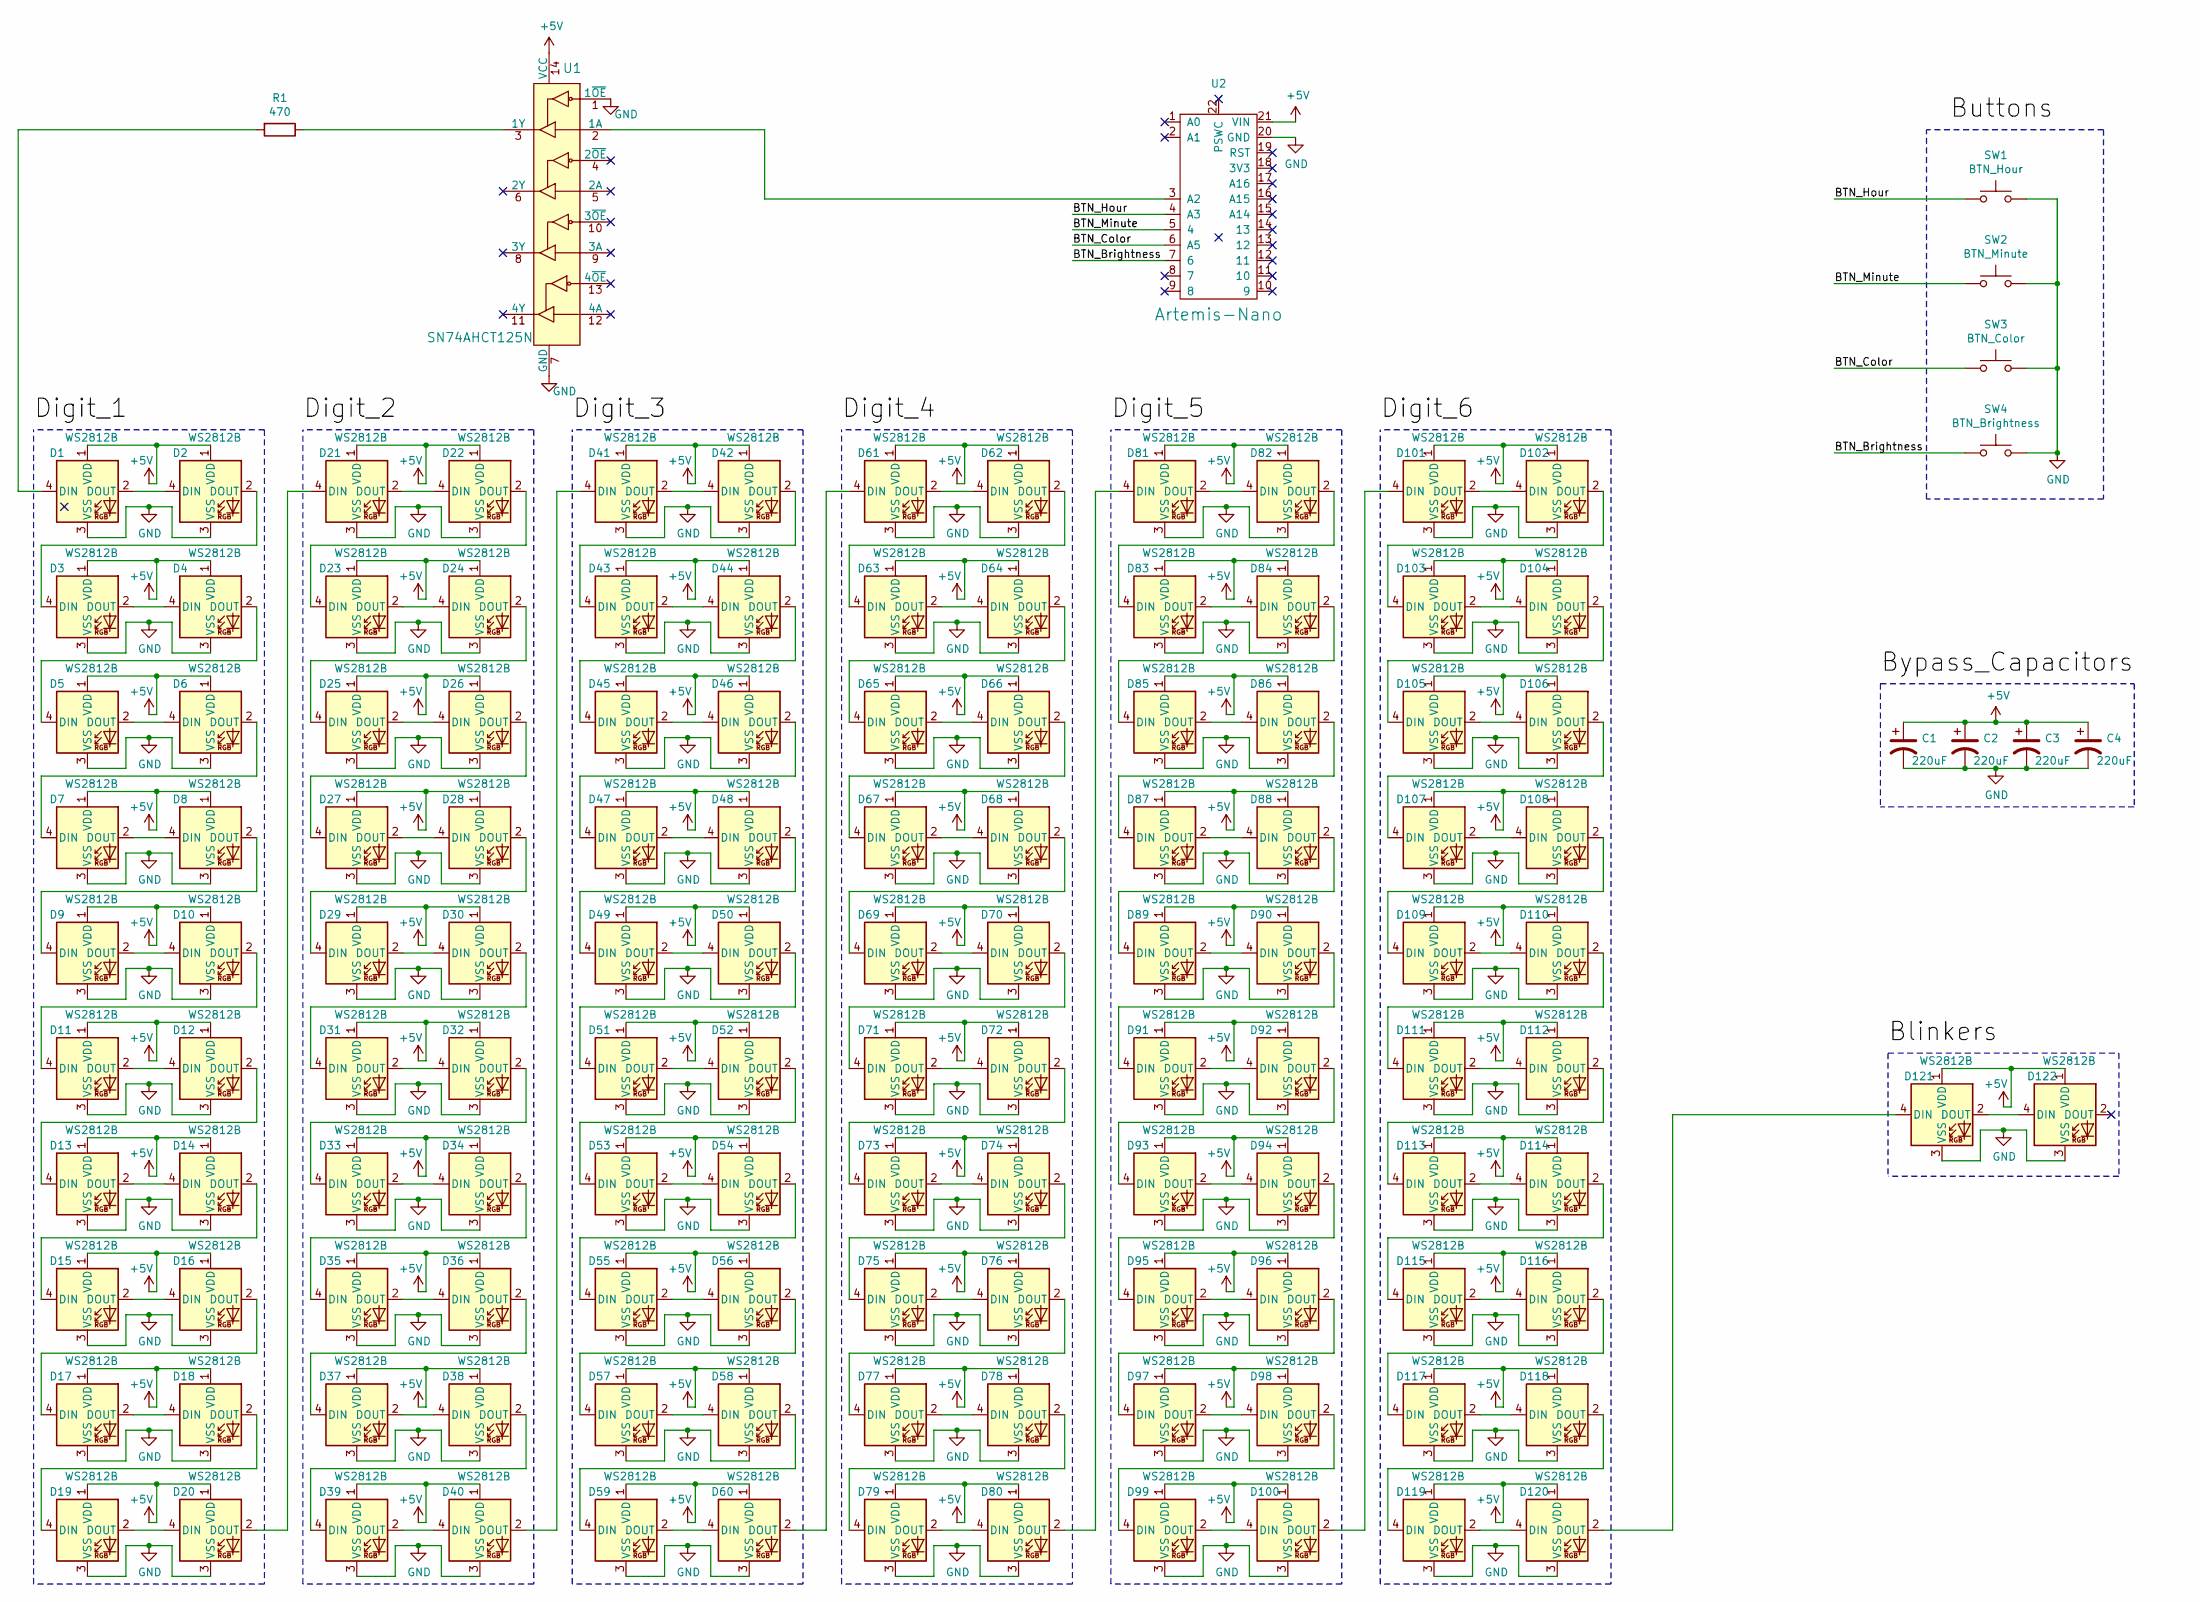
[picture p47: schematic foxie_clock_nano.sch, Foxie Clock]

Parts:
C1, C2, C3, C4: 220uF; CP_Elec_6.3x7.7; LCSC C127327
D1, D2, D3, D4, D5, D6, D7, D8, D9, D10, D11, D12, D13, D14, D15, D16, D17, D18, D19, D20, D21, D22, D23, D24, D25, D26, D27, D28, D29, D30, D31, D32, D33, D34, D35, D36, D37, D38, D39, D40, D41, D42, D43, D44, D45, D46, D47, D48, D49, D50, D51, D52, D53, D54, D55, D56, D57, D58, D59, D60, D61, D62, D63, D64, D65, D66, D67, D68, D69, D70, D71, D72, D73, D74, D75, D76, D77, D78, D79, D80, D81, D82, D83, D84, D85, D86, D87, D88, D89, D90, D91, D92, D93, D94, D95, D96, D97, D98, D99, D100, D101, D102, D103, D104, D105, D106, D107, D108, D109, D110, D111, D112, D113, D114, D115, D116, D117, D118, D119, D120, D121, D122: WS2812B; LED_WS2812B_PLCC4_5.0x5.0mm_P3.2mm; LCSC C114586
R1: 470; R_1206_3216Metric; LCSC C25383
SW1: BTN_Hour; SW_Tactile_SPST_Angled_PTS645Vx58-2LFS
SW2: BTN_Minute; SW_Tactile_SPST_Angled_PTS645Vx58-2LFS
SW3: BTN_Color; SW_Tactile_SPST_Angled_PTS645Vx58-2LFS
SW4: BTN_Brightness; SW_Tactile_SPST_Angled_PTS645Vx58-2LFS
U1: SN74AHCT125N; TSSOP-14_4.4x5mm_P0.65mm; LCSC C36365
U2: Artemis-Nano

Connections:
+5V: C1.1, C2.1, C3.1, C4.1, D1.1 (VDD), D2.1 (VDD), D3.1 (VDD), D4.1 (VDD), D5.1 (VDD), D6.1 (VDD), D7.1 (VDD), D8.1 (VDD), D9.1 (VDD), D10.1 (VDD), D11.1 (VDD), D12.1 (VDD), D13.1 (VDD), D14.1 (VDD), D15.1 (VDD), D16.1 (VDD), D17.1 (VDD), D18.1 (VDD), D19.1 (VDD), D20.1 (VDD), D21.1 (VDD), D22.1 (VDD), D23.1 (VDD), D24.1 (VDD), D25.1 (VDD), D26.1 (VDD), D27.1 (VDD), D28.1 (VDD), D29.1 (VDD), D30.1 (VDD), D31.1 (VDD), D32.1 (VDD), D33.1 (VDD), D34.1 (VDD), D35.1 (VDD), D36.1 (VDD), D37.1 (VDD), D38.1 (VDD), D39.1 (VDD), D40.1 (VDD), D41.1 (VDD), D42.1 (VDD), D43.1 (VDD), D44.1 (VDD), D45.1 (VDD), D46.1 (VDD), D47.1 (VDD), D48.1 (VDD), D49.1 (VDD), D50.1 (VDD), D51.1 (VDD), D52.1 (VDD), D53.1 (VDD), D54.1 (VDD), D55.1 (VDD), D56.1 (VDD), D57.1 (VDD), D58.1 (VDD), D59.1 (VDD), D60.1 (VDD), D61.1 (VDD), D62.1 (VDD), D63.1 (VDD), D64.1 (VDD), D65.1 (VDD), D66.1 (VDD), D67.1 (VDD), D68.1 (VDD), D69.1 (VDD), D70.1 (VDD), D71.1 (VDD), D72.1 (VDD), D73.1 (VDD), D74.1 (VDD), D75.1 (VDD), D76.1 (VDD), D77.1 (VDD), D78.1 (VDD), D79.1 (VDD), D80.1 (VDD), D81.1 (VDD), D82.1 (VDD), D83.1 (VDD), D84.1 (VDD), D85.1 (VDD), D86.1 (VDD), D87.1 (VDD), D88.1 (VDD), D89.1 (VDD), D90.1 (VDD), D91.1 (VDD), D92.1 (VDD), D93.1 (VDD), D94.1 (VDD), D95.1 (VDD), D96.1 (VDD), D97.1 (VDD), D98.1 (VDD), D99.1 (VDD), D100.1 (VDD), D101.1 (VDD), D102.1 (VDD), D103.1 (VDD), D104.1 (VDD), D105.1 (VDD), D106.1 (VDD), D107.1 (VDD), D108.1 (VDD), D109.1 (VDD), D110.1 (VDD), D111.1 (VDD), D112.1 (VDD), D113.1 (VDD), D114.1 (VDD), D115.1 (VDD), D116.1 (VDD), D117.1 (VDD), D118.1 (VDD), D119.1 (VDD), D120.1 (VDD), D121.1 (VDD), D122.1 (VDD), U1.14 (VCC), U2.21 (VIN)
/BTN_Brightness: SW4.1, U2.7 (6)
/BTN_Color: SW3.1, U2.6 (A5)
/BTN_Hour: SW1.1, U2.4 (A3)
/BTN_Minute: SW2.1, U2.5 (4)
GND: C1.2, C2.2, C3.2, C4.2, D1.3 (VSS), D2.3 (VSS), D3.3 (VSS), D4.3 (VSS), D5.3 (VSS), D6.3 (VSS), D7.3 (VSS), D8.3 (VSS), D9.3 (VSS), D10.3 (VSS), D11.3 (VSS), D12.3 (VSS), D13.3 (VSS), D14.3 (VSS), D15.3 (VSS), D16.3 (VSS), D17.3 (VSS), D18.3 (VSS), D19.3 (VSS), D20.3 (VSS), D21.3 (VSS), D22.3 (VSS), D23.3 (VSS), D24.3 (VSS), D25.3 (VSS), D26.3 (VSS), D27.3 (VSS), D28.3 (VSS), D29.3 (VSS), D30.3 (VSS), D31.3 (VSS), D32.3 (VSS), D33.3 (VSS), D34.3 (VSS), D35.3 (VSS), D36.3 (VSS), D37.3 (VSS), D38.3 (VSS), D39.3 (VSS), D40.3 (VSS), D41.3 (VSS), D42.3 (VSS), D43.3 (VSS), D44.3 (VSS), D45.3 (VSS), D46.3 (VSS), D47.3 (VSS), D48.3 (VSS), D49.3 (VSS), D50.3 (VSS), D51.3 (VSS), D52.3 (VSS), D53.3 (VSS), D54.3 (VSS), D55.3 (VSS), D56.3 (VSS), D57.3 (VSS), D58.3 (VSS), D59.3 (VSS), D60.3 (VSS), D61.3 (VSS), D62.3 (VSS), D63.3 (VSS), D64.3 (VSS), D65.3 (VSS), D66.3 (VSS), D67.3 (VSS), D68.3 (VSS), D69.3 (VSS), D70.3 (VSS), D71.3 (VSS), D72.3 (VSS), D73.3 (VSS), D74.3 (VSS), D75.3 (VSS), D76.3 (VSS), D77.3 (VSS), D78.3 (VSS), D79.3 (VSS), D80.3 (VSS), D81.3 (VSS), D82.3 (VSS), D83.3 (VSS), D84.3 (VSS), D85.3 (VSS), D86.3 (VSS), D87.3 (VSS), D88.3 (VSS), D89.3 (VSS), D90.3 (VSS), D91.3 (VSS), D92.3 (VSS), D93.3 (VSS), D94.3 (VSS), D95.3 (VSS), D96.3 (VSS), D97.3 (VSS), D98.3 (VSS), D99.3 (VSS), D100.3 (VSS), D101.3 (VSS), D102.3 (VSS), D103.3 (VSS), D104.3 (VSS), D105.3 (VSS), D106.3 (VSS), D107.3 (VSS), D108.3 (VSS), D109.3 (VSS), D110.3 (VSS), D111.3 (VSS), D112.3 (VSS), D113.3 (VSS), D114.3 (VSS), D115.3 (VSS), D116.3 (VSS), D117.3 (VSS), D118.3 (VSS), D119.3 (VSS), D120.3 (VSS), D121.3 (VSS), D122.3 (VSS), SW1.2, SW2.2, SW3.2, SW4.2, U1.1 (1~OE), U1.7 (GND), U2.20 (GND)
unnamed: D1.2 (DOUT), D2.4 (DIN)
unnamed: D1.4 (DIN), R1.2
unnamed: D2.2 (DOUT), D3.4 (DIN)
unnamed: D3.2 (DOUT), D4.4 (DIN)
unnamed: D4.2 (DOUT), D5.4 (DIN)
unnamed: D5.2 (DOUT), D6.4 (DIN)
unnamed: D6.2 (DOUT), D7.4 (DIN)
unnamed: D7.2 (DOUT), D8.4 (DIN)
unnamed: D8.2 (DOUT), D9.4 (DIN)
unnamed: D10.2 (DOUT), D11.4 (DIN)
unnamed: D9.2 (DOUT), D10.4 (DIN)
unnamed: D11.2 (DOUT), D12.4 (DIN)
unnamed: D12.2 (DOUT), D13.4 (DIN)
unnamed: D13.2 (DOUT), D14.4 (DIN)
unnamed: D14.2 (DOUT), D15.4 (DIN)
unnamed: D15.2 (DOUT), D16.4 (DIN)
unnamed: D16.2 (DOUT), D17.4 (DIN)
unnamed: D17.2 (DOUT), D18.4 (DIN)
unnamed: D18.2 (DOUT), D19.4 (DIN)
unnamed: D19.2 (DOUT), D20.4 (DIN)
unnamed: D20.2 (DOUT), D21.4 (DIN)
unnamed: D21.2 (DOUT), D22.4 (DIN)
unnamed: D22.2 (DOUT), D23.4 (DIN)
unnamed: D23.2 (DOUT), D24.4 (DIN)
unnamed: D24.2 (DOUT), D25.4 (DIN)
unnamed: D25.2 (DOUT), D26.4 (DIN)
unnamed: D26.2 (DOUT), D27.4 (DIN)
unnamed: D27.2 (DOUT), D28.4 (DIN)
unnamed: D28.2 (DOUT), D29.4 (DIN)
unnamed: D29.2 (DOUT), D30.4 (DIN)
unnamed: D30.2 (DOUT), D31.4 (DIN)
unnamed: D31.2 (DOUT), D32.4 (DIN)
unnamed: D32.2 (DOUT), D33.4 (DIN)
unnamed: D33.2 (DOUT), D34.4 (DIN)
unnamed: D34.2 (DOUT), D35.4 (DIN)
unnamed: D35.2 (DOUT), D36.4 (DIN)
unnamed: D36.2 (DOUT), D37.4 (DIN)
unnamed: D37.2 (DOUT), D38.4 (DIN)
unnamed: D38.2 (DOUT), D39.4 (DIN)
unnamed: D39.2 (DOUT), D40.4 (DIN)
unnamed: D40.2 (DOUT), D41.4 (DIN)
unnamed: D41.2 (DOUT), D42.4 (DIN)
unnamed: D42.2 (DOUT), D43.4 (DIN)
unnamed: D43.2 (DOUT), D44.4 (DIN)
unnamed: D44.2 (DOUT), D45.4 (DIN)
unnamed: D45.2 (DOUT), D46.4 (DIN)
unnamed: D46.2 (DOUT), D47.4 (DIN)
unnamed: D47.2 (DOUT), D48.4 (DIN)
unnamed: D48.2 (DOUT), D49.4 (DIN)
unnamed: D49.2 (DOUT), D50.4 (DIN)
unnamed: D50.2 (DOUT), D51.4 (DIN)
unnamed: D51.2 (DOUT), D52.4 (DIN)
unnamed: D52.2 (DOUT), D53.4 (DIN)
unnamed: D53.2 (DOUT), D54.4 (DIN)
unnamed: D54.2 (DOUT), D55.4 (DIN)
unnamed: D55.2 (DOUT), D56.4 (DIN)
unnamed: D56.2 (DOUT), D57.4 (DIN)
unnamed: D57.2 (DOUT), D58.4 (DIN)
unnamed: D58.2 (DOUT), D59.4 (DIN)
unnamed: D59.2 (DOUT), D60.4 (DIN)
unnamed: D60.2 (DOUT), D61.4 (DIN)
unnamed: D61.2 (DOUT), D62.4 (DIN)
unnamed: D62.2 (DOUT), D63.4 (DIN)
unnamed: D63.2 (DOUT), D64.4 (DIN)
unnamed: D64.2 (DOUT), D65.4 (DIN)
unnamed: D65.2 (DOUT), D66.4 (DIN)
unnamed: D66.2 (DOUT), D67.4 (DIN)
unnamed: D67.2 (DOUT), D68.4 (DIN)
unnamed: D68.2 (DOUT), D69.4 (DIN)
unnamed: D69.2 (DOUT), D70.4 (DIN)
unnamed: D70.2 (DOUT), D71.4 (DIN)
unnamed: D71.2 (DOUT), D72.4 (DIN)
unnamed: D72.2 (DOUT), D73.4 (DIN)
unnamed: D73.2 (DOUT), D74.4 (DIN)
unnamed: D74.2 (DOUT), D75.4 (DIN)
unnamed: D75.2 (DOUT), D76.4 (DIN)
unnamed: D76.2 (DOUT), D77.4 (DIN)
unnamed: D77.2 (DOUT), D78.4 (DIN)
unnamed: D78.2 (DOUT), D79.4 (DIN)
unnamed: D79.2 (DOUT), D80.4 (DIN)
unnamed: D80.2 (DOUT), D81.4 (DIN)
unnamed: D81.2 (DOUT), D82.4 (DIN)
unnamed: D82.2 (DOUT), D83.4 (DIN)
unnamed: D83.2 (DOUT), D84.4 (DIN)
unnamed: D84.2 (DOUT), D85.4 (DIN)
unnamed: D85.2 (DOUT), D86.4 (DIN)
unnamed: D86.2 (DOUT), D87.4 (DIN)
unnamed: D87.2 (DOUT), D88.4 (DIN)
unnamed: D88.2 (DOUT), D89.4 (DIN)
unnamed: D89.2 (DOUT), D90.4 (DIN)
unnamed: D90.2 (DOUT), D91.4 (DIN)
unnamed: D91.2 (DOUT), D92.4 (DIN)
unnamed: D92.2 (DOUT), D93.4 (DIN)
unnamed: D93.2 (DOUT), D94.4 (DIN)
unnamed: D94.2 (DOUT), D95.4 (DIN)
unnamed: D95.2 (DOUT), D96.4 (DIN)
unnamed: D96.2 (DOUT), D97.4 (DIN)
unnamed: D97.2 (DOUT), D98.4 (DIN)
unnamed: D98.2 (DOUT), D99.4 (DIN)
unnamed: D100.2 (DOUT), D101.4 (DIN)
unnamed: D99.2 (DOUT), D100.4 (DIN)
unnamed: D101.2 (DOUT), D102.4 (DIN)
unnamed: D102.2 (DOUT), D103.4 (DIN)
unnamed: D103.2 (DOUT), D104.4 (DIN)
unnamed: D104.2 (DOUT), D105.4 (DIN)
unnamed: D105.2 (DOUT), D106.4 (DIN)
unnamed: D106.2 (DOUT), D107.4 (DIN)
unnamed: D107.2 (DOUT), D108.4 (DIN)
unnamed: D108.2 (DOUT), D109.4 (DIN)
unnamed: D109.2 (DOUT), D110.4 (DIN)
unnamed: D110.2 (DOUT), D111.4 (DIN)
unnamed: D111.2 (DOUT), D112.4 (DIN)
unnamed: D112.2 (DOUT), D113.4 (DIN)
unnamed: D113.2 (DOUT), D114.4 (DIN)
unnamed: D114.2 (DOUT), D115.4 (DIN)
unnamed: D115.2 (DOUT), D116.4 (DIN)
unnamed: D116.2 (DOUT), D117.4 (DIN)
unnamed: D117.2 (DOUT), D118.4 (DIN)
unnamed: D118.2 (DOUT), D119.4 (DIN)
unnamed: D119.2 (DOUT), D120.4 (DIN)
unnamed: D120.2 (DOUT), D121.4 (DIN)
unnamed: D121.2 (DOUT), D122.4 (DIN)
unnamed: R1.1, U1.3 (1Y)
unnamed: U1.2 (1A), U2.3 (A2)

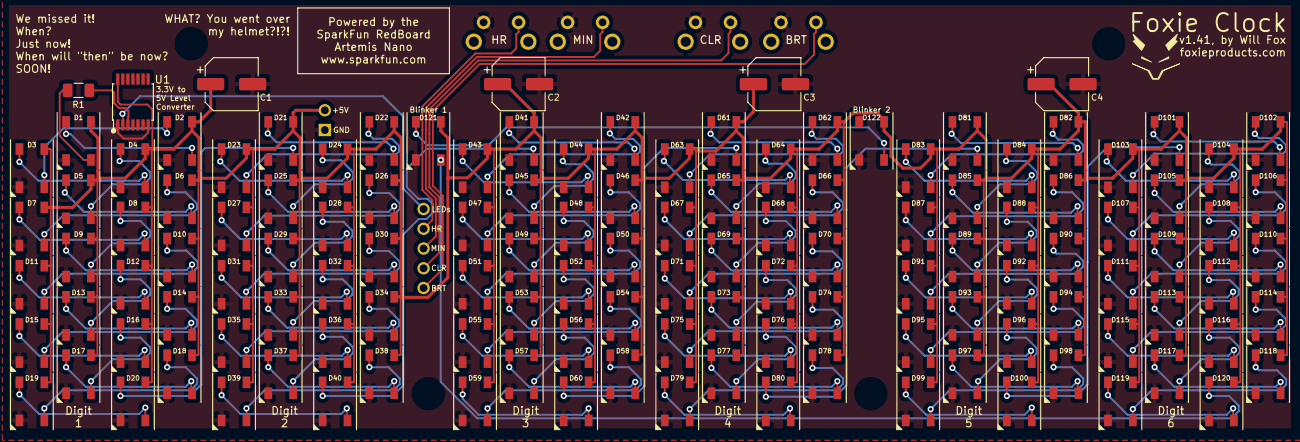
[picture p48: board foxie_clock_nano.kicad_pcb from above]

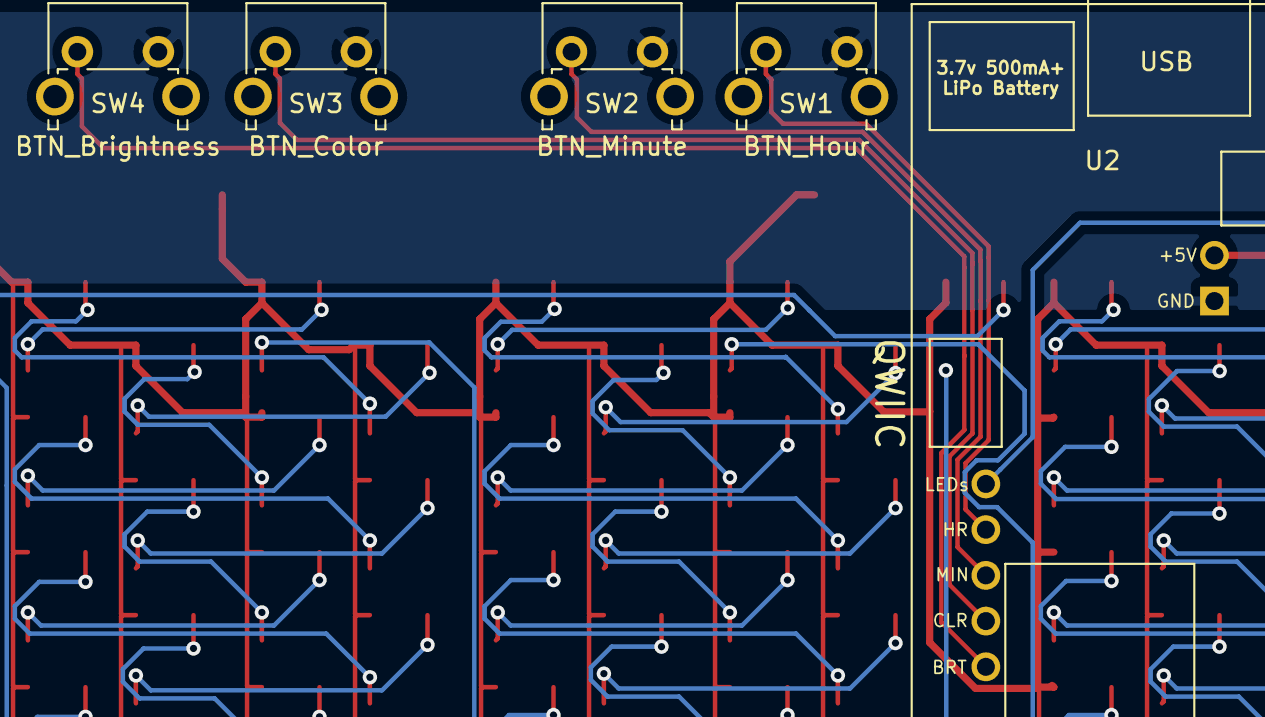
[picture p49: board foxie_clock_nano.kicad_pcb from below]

Board: 2 copper layers, 133 parts (5 on the bottom side), 130 nets.

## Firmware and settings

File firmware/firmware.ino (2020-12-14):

#define FOXIE_ARTEMIS

enum HardwareConfig_e
{
    PIN_FOR_LEDS = 2, // pin "A2" -- "LEDs" on PCB
    NUM_LEDS = 122,
    NUM_DIGITS = 6,
    NUM_BTNS = 4,

    DELAY_FOR_COMBINATION_BUTTONS = 750,
};

enum Pins_e 
{
    PIN_BTN_H = 3, // pin "A3" -- "HR" on PCB
    PIN_BTN_M = 4, // pin "4" -- "MIN" on PCB
    PIN_BTN_C = 5, // pin "A5" -- "CLR" on PCB
    PIN_BTN_B = 6, // pin "6" -- "BRT" on PCB
};

#include "clock.hpp"

void setup()
{
    // The idea in this file is to keep it mostly Arduino-specific,
    // while all "real" clock functionality is contained within the
    // Clock class in a very "clean" way. That's the idea, anyway...

    Clock clock;
    while (true)
    {
        clock.Loop();
    }
}

void loop()
{
    // never used, see Clock::Loop() in clock.hpp instead
}

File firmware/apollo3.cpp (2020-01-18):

// This provides the functionality for Apollo3 devices.

#if defined(AM_PART_APOLLO3)

#include <ap3_types.h>
#include <am_hal_gpio.h>

#include "Adafruit_NeoPixel.h"

// The timing method used to control the NeoPixels
// TODO: Implement something better (interrupts, DMA, etc)
#define PIN_METHOD_FAST_GPIO

/*!
  @brief   Unset the NeoPixel output pad number.
  @param   pad  Apollo3 pad number
*/
void Adafruit_NeoPixel::apollo3UnsetPad(ap3_gpio_pad_t pad) {
#if defined(PIN_METHOD_FAST_GPIO)
  // Unconfigure the pad for Fast GPIO.
  am_hal_gpio_fastgpio_disable(pad);
#endif
}

/*!
  @brief   Set the NeoPixel output pad number.
  @param   pad  Apollo3 pad number
*/
void Adafruit_NeoPixel::apollo3SetPad(ap3_gpio_pad_t pad) {
#if defined(PIN_METHOD_FAST_GPIO)
  // Configure the pad to be used for Fast GPIO.
  am_hal_gpio_fastgpio_disable(pad);
  am_hal_gpio_fastgpio_clr(pad);

  am_hal_gpio_fast_pinconfig((uint64_t)0x1 << pad,
                             g_AM_HAL_GPIO_OUTPUT, 0);
  // uint32_t ui32Ret = am_hal_gpio_fast_pinconfig((uint64_t)0x1 << pad,
  //                                               g_AM_HAL_GPIO_OUTPUT, 0);
  // if (ui32Ret) {
  //   am_util_stdio_printf(
  //     "Error returned from am_hal_gpio_fast_pinconfig() = .\n", ui32Ret);
  // }
#endif
}

// Note - The timings used below are based on the Arduino Zero,
//   Gemma/Trinket M0 code.

/*!
  @brief   Transmit pixel data in RAM to NeoPixels.
  @note    The current design is a quick hack and should be replaced with
           a more robust timing mechanism.
*/
void Adafruit_NeoPixel::apollo3Show(
  ap3_gpio_pad_t pad, uint8_t *pixels, uint32_t numBytes, boolean is800KHz) {

  uint8_t  *ptr, *end, p, bitMask;
  ptr     =  pixels;
  end     =  ptr + numBytes;
  p       = *ptr++;
  bitMask =  0x80;

#if defined(PIN_METHOD_FAST_GPIO)

  // disable interrupts
  am_hal_interrupt_master_disable();

#ifdef NEO_KHZ400 // 800 KHz check needed only if 400 KHz support enabled
  if(is800KHz) {
#endif
    for(;;) {
      am_hal_gpio_fastgpio_set(pad);
      //asm("nop; nop; nop; nop; nop; nop; nop; nop;");
      asm("nop; nop; nop; nop; nop; nop; nop; nop; nop; nop; nop; nop;");
      if(p & bitMask) {
        asm("nop; nop; nop; nop; nop; nop; nop; nop;"
            "nop; nop; nop; nop; nop; nop; nop; nop;"
            "nop; nop; nop; nop;");
        am_hal_gpio_fastgpio_clr(pad);
      } else {
        am_hal_gpio_fastgpio_clr(pad);
        asm("nop; nop; nop; nop; nop; nop; nop; nop;"
            "nop; nop; nop; nop; nop; nop; nop; nop;"
            "nop; nop; nop; nop;");
      }
      if(bitMask >>= 1) {
	asm("nop; nop; nop; nop; nop; nop; nop; nop; nop;");
      } else {
        if(ptr >= end) break;
        p       = *ptr++;
        bitMask = 0x80;
      }
    }
#ifdef NEO_KHZ400
  } else { // 400 KHz bitstream
    // NOTE - These timings may need to be tweaked
    for(;;) {
      am_hal_gpio_fastgpio_set(pad);
      asm("nop;");
      if(p & bitMask) {
        asm("nop; nop; nop; nop; nop; nop; nop; nop;"
            "nop; nop; nop; nop; nop; nop; nop; nop;"
            "nop; nop; nop; nop; nop; nop; nop; nop;"
            "nop; nop; nop;");
        am_hal_gpio_fastgpio_clr(pad);
      } else {
        am_hal_gpio_fastgpio_clr(pad);
        asm("nop; nop; nop; nop; nop; nop; nop; nop;"
            "nop; nop; nop; nop; nop; nop; nop; nop;"
            "nop; nop; nop; nop; nop; nop; nop; nop;"
            "nop; nop; nop;");
      }
      asm("nop; nop; nop; nop; nop; nop; nop; nop;"
          "nop; nop; nop; nop; nop; nop; nop; nop;"
          "nop; nop; nop; nop; nop; nop; nop; nop;"
          "nop; nop; nop; nop; nop; nop; nop; nop;"
          "nop; nop; nop; nop; nop; nop; nop; nop;"
          "nop; nop; nop; nop; nop; nop; nop; nop;");
      if(bitMask >>= 1) {
        asm("nop; nop; nop; nop; nop; nop; nop;");
      } else {
        if(ptr >= end) break;
        p       = *ptr++;
        bitMask = 0x80;
      }
    }
  }

  // re-enable interrupts
  am_hal_interrupt_master_enable();

#endif // NEO_KHZ400
#endif // PIN_METHOD_FAST_GPIO
}

#endif // AM_PART_APOLLO3

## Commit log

2020-01-04 Adding KiCad files for 1.4 board
    [foxie_clock_nano-B_Cu.gbr, foxie_clock_nano-B_Mask.gbr, foxie_clock_nano-B_SilkS.gbr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]
2020-01-11 Improving timing to eliminate occasional green first LED
2020-01-12 Add slight delay in timing to hopefully resolve occasional bad pixel color... really need a better solution
    [apollo3.cpp]
2020-01-14 Another timing tweak to fix rare wrong color LEDs... until better method is implemented.
    [apollo3.cpp]
2020-01-14 Removing .step file in favor of updated .step file to be on thingiverse
    [v1.4_foxie_clock_nano.step]
2020-01-14 Removing backup KiCad PCB from source control
2020-01-14 Adding acrylic lid SVG files, one for 1.5mm and one for 1.65mm holes
2020-01-18 Button cleanup, refactored debouncing logic and switched to callback lambda functions for button events
2020-01-18 Much improved button debouncing and handler setup, with press, repeat, and release events
2020-01-18 Button behavior improvements: Hour button must be held for 1s to enter/exit 'Set Time' mode.
2020-01-19 Fix compile issue caused by header file reorganization due to clang formatting
    [digit_manager.hpp, firmware.ino]
2020-01-19 Cleanup, switching naked pointers to shared_ptr
2020-01-19 Updating lid laser cutting SVG files
2020-01-19 Renaming acrylic to laser_cutting
2020-01-21 Adding images for assembly
2020-01-21 Adding image for assembled, powered-on clock
2020-01-21 Removing black border from PCB render
2020-01-22 Adding missing step to select the correct Board
2020-01-28 Increasing laser cut width to 5.1mm to account for minor inconsistencies and make tolerance less tight
2020-02-10 Add a couple of example lines for changing the animation mode
2020-02-11 Add new ANIM_CYCLE_FLOW_LEFT animation type, allow repeat for Minute button for setting time
2020-02-11 Flow animation should redraw when re-entering normal clock mode
2020-02-11 Add functionality for M button to cycle animation types
2020-02-11 Update USAGE.md
    Add animation mode button documentation
2020-02-14 Crop case renders
2020-02-23 Added support for DC3231 battery backup clock module
2020-02-24 Minor changes to nbJosh's DS3231 commit to fix formatting and global use. Wire is initialized by default now as well.
    [firmware.ino, rtc_hal_apollo3.cpp]
2020-03-01 Update ASSEMBLY.md
    Add the use of a utility knife to lift the edge of the protective paper, and use a fingernail to lift the edge of the internal areas of the "0" and the "8".
2020-03-08 Fix bug with blinkers staying on between switching display modes from command handler
2020-03-08 Fix bug with animation modes being set way over the maximum and the button not correcting it when pressed, and use Clock::SetBrightness to unify functionality between Brightness button and app contro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
    [firmware.ino]
2020-07-24 Fix - Color setting getting way too large. Oops!
    [firmware.ino]
2020-07-24 Animation: Rainbow is added. The "color" button functions as "pause"
2020-07-24 Add setting for flipping the display, and improve flipping method
    [firmware.ino]
2020-07-25 Add RTC hundredth/millis functions
2020-07-30 Minor wording change on PCB
    [foxie_clock_nano.kicad_pcb]
2020-07-30 Edge-lit mode fades should also fade IN the new digit. Pixel mode doesn't look quite right with a fade-in on the new digit so for now, it's excluded.
    [digit_manager.hpp, firmware.ino]
2020-09-16 Improve Button class to store created buttons This allows a single call to CheckAll() instead of multiple Check()s
2020-09-16 Add sleep mode While holding M, press and release B. The digits will fade out. Press any button to wake up.
2020-12-07 Solve issue with prematurely setting the current button state on change
2020-12-07 Fix issue with setting time interfering with fading transitions
    [firmware.ino]
2020-12-13 Back to basics, remove everything except digit display. BLE is gone. Removing BLE because I don't plan to have it in the next version of the clock and I simply have not had the time to work on it or 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
    [digit_manager.hpp, firmware.ino, rtc_hal_apollo3.cpp]
2020-12-13 Entirely refactored button handling code
2020-12-13 Brightness, Color, and Toggle buttons are now working.
2020-12-13 Improve behavior when switching between display types
2020-12-13 Cleanup and make Buttons exclusive
2020-12-14 Add ability to flip display by pressing C+B
    [firmware.ino]
2020-12-14 Fix bug with Blinkers turning off LEDs incorrectly, bug fixes mode
    [blinkers.hpp]
2020-12-14 Turn off blinkers before flipping display or switching PXL/Edge lit
    [blinkers.hpp]
2020-12-15 Restore code to clear the EEPROM on a new board.
2020-12-15 Updating digit assembly images
2020-12-17 Combine Digits and current/last numbers displayed into struct
2020-12-17 Fix issue with combo buttons not disabling other buttons
2020-12-17 Double the speed the Minute button advances
2020-12-17 Display 12/24H mode when switching
